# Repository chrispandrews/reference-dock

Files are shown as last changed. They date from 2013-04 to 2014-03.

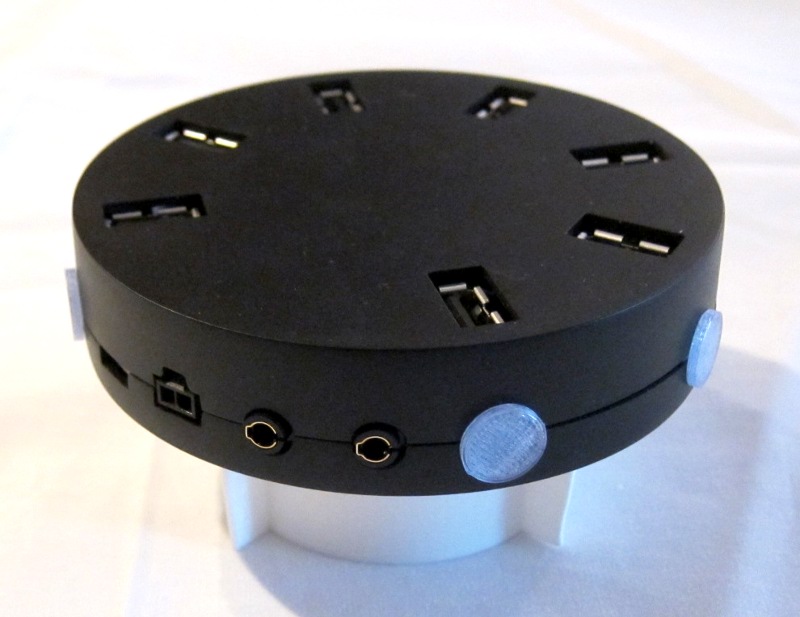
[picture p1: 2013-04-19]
docs/Dock_scaled.JPG

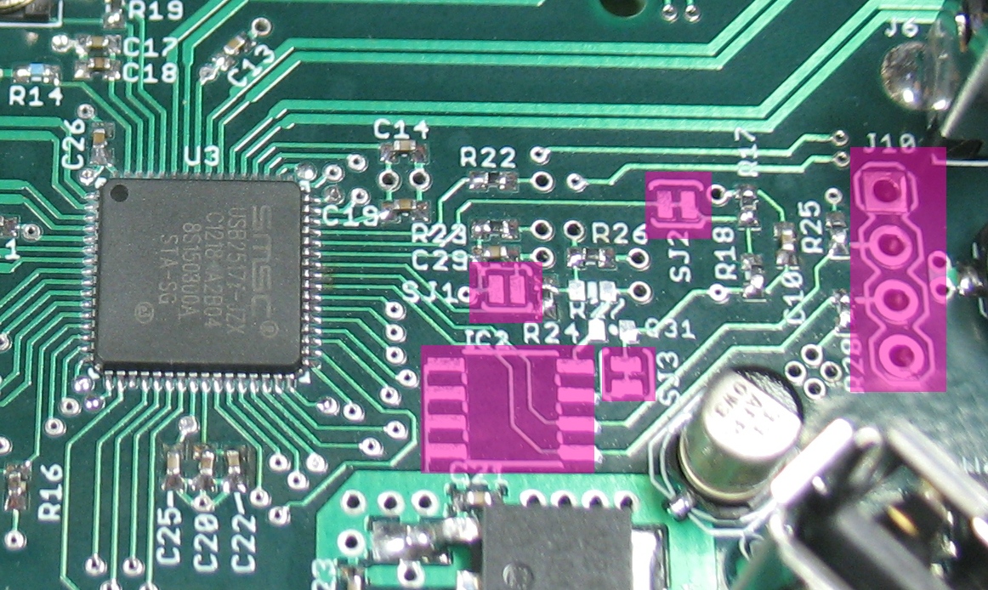
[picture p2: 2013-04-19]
docs/Dock_jumpers.JPG

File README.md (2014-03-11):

OpenXC Dock
===========

This repository is a part of the [OpenXC][] project.

This repository contains the documentation and open source design files for an
example OpenXC accessory dock, originally created by Ford.

The OpenXC Dock is a hub for connecting multiple USB accessories to an Android
tablet or phone. Since each accessory uses USB to communicate with the host, the
Dock is essentially a USB hub. The Dock receives power from the vehicle, and
regulates this power to a steady +5V for use by the accessory.

There is a [gallery of
photos](https://plus.google.com/photos/108408483770573977605/albums/5989365070748059233)
of the prototype dock.

### Buttons, Headers, Jumpers

*	JP2 - This jumper connects the +5V pin of the USB Micro connector to the +5V
	supply on the Dock. Connected by default. This enables charging of the
	Android device as well as standalone Dock usage with a PC.
*	SJ1 - USB hub reset - short this jumper to keep the USB hub in reset.
	Normally open.
*	SJ2 - Allows the USB hub to sense it's power state from the USB Micro
	connector. Normally closed by trace.
*	J10 - I2C - Exposes the i2c bus used by the USB hub for configuration
*	R35 - ID Resistor - For use with an Android device that expects a
	non-standard ID resistor in order to charge from USB OTG. The surface mount
	resistor R35 can be removed and a full-size 1/4W through hole resistor can
	be added instead.

### Known Issues

#### v0.3

*	USB D+ and D- swapped for downstream ports - An i2c EEPROM (AT24C02) was
	added to the board and soldered to J10. This allowed access to the PORT_SWAP
	register within the USB2517 hub, which enables the USB data lines to be
	swapped within the hub. Also
*	Downstream power ports are not enabled on hub poweron - The accessory USB
	connectors are not powered until a valid USB host has connected to the hub.
	Hub should be upgraded to a part with full Battery Charging support to
	enable this feature. The downstream power switches (U1, U2, U6, U7) were all
	reworked to remain permanently ON (each EN input trace was cut and the pin
	connected to +5V).
*	Downstream power ports will only flag a power fault when a host is
	connected. If an accessory malfunctions and draws too much power, the power
	switches will protect the accessory and Dock by limiting the current to
	500mA. When a host is connected, the LED for that port will light Red to
	indicate the fault. This does not occur when no host has been connected, so
	it's possible that a malfunctioning accessory will continue to draw ~500mA
	from the vehicle without alerting the user.

## License

Copyright (c) 2014 Ford Motor Company

The electrical and mechanical designs in this repository are available under the
[Creative Commons Attribution 4.0
International](http://creativecommons.org/licenses/by/4.0/deed.en_US) license.

[OpenXC]: http://openxcplatform.com

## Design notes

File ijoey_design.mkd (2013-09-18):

iJoey Design Guidelines
=======================

Below is a list of specifications for designing OpenXC iJoeys. These parameters
are specific for the components that get plugged into the size-specific Dock
ports.

**Outer Dimensions:**

* housing width: **16mm**

**Wall Thicknesses:**

* minimum case thickness: **2.54mm**
* minimum overlap thickness: **1.27mm** (overlap where two parts come together
  like clam shells)

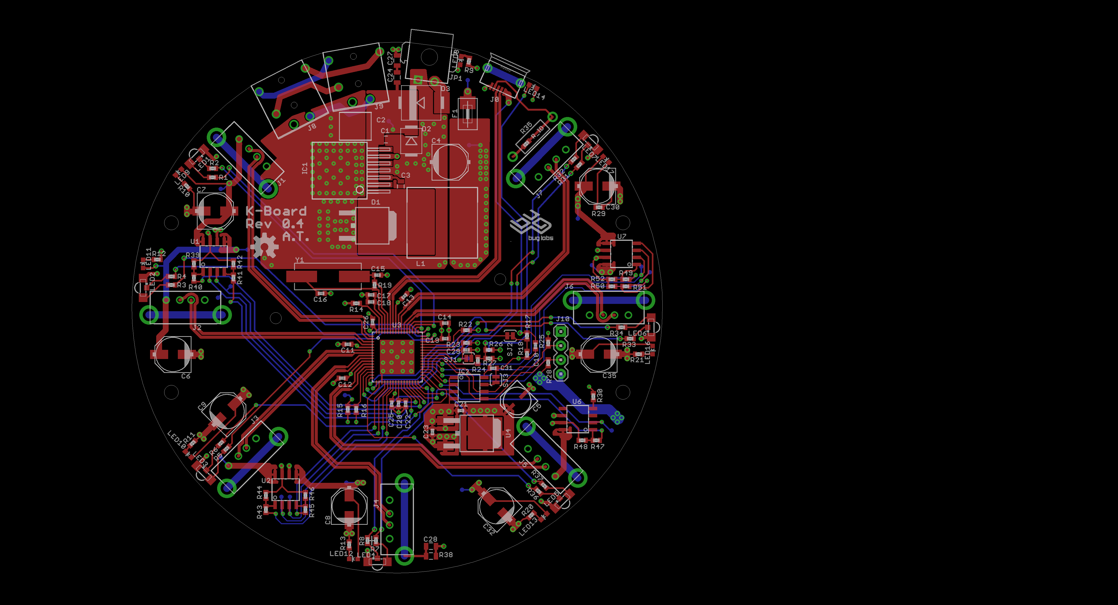
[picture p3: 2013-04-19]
schematics/Dock.brd.png

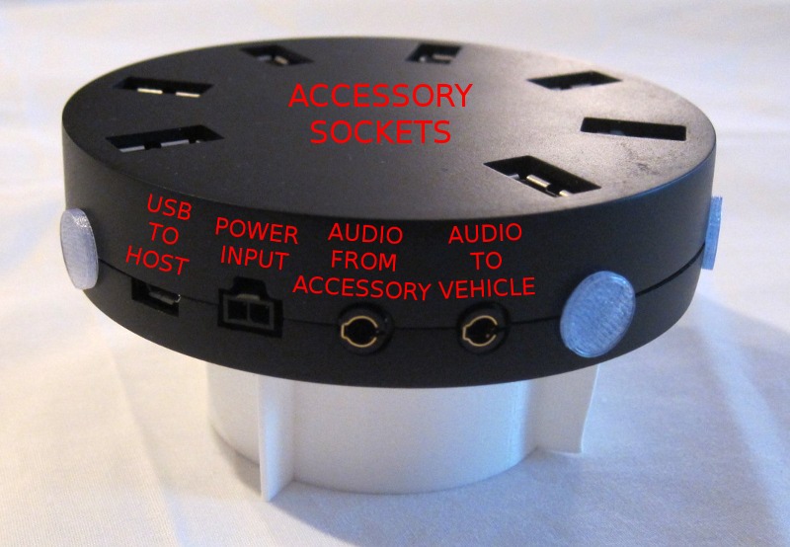
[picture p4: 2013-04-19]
docs/Dock_connectors.JPG

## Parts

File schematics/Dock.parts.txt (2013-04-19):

Partlist

Exported from K-Board.sch at 3/12/13 11:59 AM

EAGLE Version 6.1.0 Copyright (c) 1988-2012 CadSoft

Assembly variant: 

Part     Value                     Device                    Package          Library               Sheet

C1       GRM21BR71H105KA           CAP0805                   0805             BUG                   1
C2       C5750X7S2A106M            CAP2220                   2220             BUG                   1
C3       C0805C103K5RACTU          CAP0805                   0805             BUG                   1
C4       150u                      CAP_POLD                  PANASONIC_D      BUG                   1
C5       33u                       CAP_POLC                  PANASONIC_C      BUG                   1
C6       100u                      CAP_POLD                  PANASONIC_D      BUG                   1
C7       100u                      CAP_POLD                  PANASONIC_D      BUG                   1
C8       100u                      CAP_POLD                  PANASONIC_D      BUG                   1
C9       100u                      CAP_POLD                  PANASONIC_D      BUG                   1
C10      0.1                       CAP0402-CAP               0402-CAP         BUG                   1
C11      0.1                       CAP0402-CAP               0402-CAP         BUG                   1
C12      0.1                       CAP0402-CAP               0402-CAP         BUG                   1
C13      0.1                       CAP0402-CAP               0402-CAP         BUG                   1
C14      0.1                       CAP0402-CAP               0402-CAP         BUG                   1
C15      18p                       CAP0402-CAP               0402-CAP         BUG                   1
C16      18p                       CAP0402-CAP               0402-CAP         BUG                   1
C17      1                         CAP0402-CAP               0402-CAP         BUG                   1
C18      0.1                       CAP0402-CAP               0402-CAP         BUG                   1
C19      0.1                       CAP0402-CAP               0402-CAP         BUG                   1
C20      0.1                       CAP0402-CAP               0402-CAP         BUG                   1
C21      22n                       CAP0402-CAP               0402-CAP         BUG                   1
C22      1                         CAP0402-CAP               0402-CAP         BUG                   1
C23      0.1                       CAP0402-CAP               0402-CAP         BUG                   1
C24      0.47u                     CAP0805                   0805             BUG                   1
C25      0.1                       CAP0402-CAP               0402-CAP         BUG                   1
C26      0.1                       CAP0402-CAP               0402-CAP         BUG                   1
C27      0.47                      CAP0805                   0805             BUG                   1
C28      4.7n                      CAP0805                   0805             BUG                   1
C29      0.1                       CAP0402-CAP               0402-CAP         BUG                   1
C30      100u                      CAP_POLD                  PANASONIC_D      BUG                   1
C31      0.1                       CAP0402-CAP               0402-CAP         BUG                   1
C32      100u                      CAP_POLD                  PANASONIC_D      BUG                   1
C35      100u                      CAP_POLD                  PANASONIC_D      BUG                   1
D1       50WQ10FNPBF               DIODE_COMMON_CAT-DPAK     V-REG_DPACK      BUG                   1
D2       SMBJ36CA                  DIODE-TVS-SMB             SMB-DIODE        BUG                   1
D3       MBRS540T3G                DIODESMC/DO-214AB         SMC              SparkFun-DiscreteSemi 1
F1       MF-MSMF110/16-2           PTCFUSE-1812              1812             adafruit              1
IC1      LM22678                   LM22678                   TO-263           BUG                   1
IC2      ATMEL-AT24C02B-SS         ATMEL-AT24C02B-SS         SOIC8            BUG                   1
J0       USB_MINIB_SHIELD-10118193 USB_MINIB_SHIELD-10118193 10118193         BUG                   1
J1       USB-A-S-RA-VERT           USB-A-S-RA-VERT           USB-A-TH-VERT    BUG                   1
J2       USB-A-S-RA-VERT           USB-A-S-RA-VERT           USB-A-TH-VERT    BUG                   1
J3       USB-A-S-RA-VERT           USB-A-S-RA-VERT           USB-A-TH-VERT    BUG                   1
J4       USB-A-S-RA-VERT           USB-A-S-RA-VERT           USB-A-TH-VERT    BUG                   1
J5       USB-A-S-RA-VERT           USB-A-S-RA-VERT           USB-A-TH-VERT    BUG                   1
J6       USB-A-S-RA-VERT           USB-A-S-RA-VERT           USB-A-TH-VERT    BUG                   1
J7       USB-A-S-RA-VERT           USB-A-S-RA-VERT           USB-A-TH-VERT    BUG                   1
J8       Audio INPUT               AUDIO-JACK-4PSWSJ-43515   SJ-4351X         BUG                   1
J9       Audio OUTPUT              AUDIO-JACK-4PSWSJ-43515   SJ-4351X         BUG                   1
J10      IIC                       M04PTH                    1X04             SparkFun-Connectors   1
JP1      Power                     M022-1445055-2            2-1445055-2      BUG                   1
L1       SRR1208-6R5ML             INDUCTORSRR1208           SRR1208          BUG                   1
LED1     LED_2X_COMMON_ANODE       LED_2X_COMMON_ANODE       LED_DUAL_3MMX1MM BUG                   1
LED2     LED_2X_COMMON_ANODE       LED_2X_COMMON_ANODE       LED_DUAL_3MMX1MM BUG                   1
LED3     LED_2X_COMMON_ANODE       LED_2X_COMMON_ANODE       LED_DUAL_3MMX1MM BUG                   1
LED4     LED_2X_COMMON_ANODE       LED_2X_COMMON_ANODE       LED_DUAL_3MMX1MM BUG                   1
LED5     LED_2X_COMMON_ANODE       LED_2X_COMMON_ANODE       LED_DUAL_3MMX1MM BUG                   1
LED6     LED_2X_COMMON_ANODE       LED_2X_COMMON_ANODE       LED_DUAL_3MMX1MM BUG                   1
LED7     LED_2X_COMMON_ANODE       LED_2X_COMMON_ANODE       LED_DUAL_3MMX1MM BUG                   1
LED8                               LED0603                   LED-0603         BUG                   1
LED9                               LED0603                   LED-0603         BUG                   1
LED10                              LED0603                   LED-0603         BUG                   1
LED11                              LED0603                   LED-0603         BUG                   1
LED12                              LED0603                   LED-0603         BUG                   1
LED13                              LED0603                   LED-0603         BUG                   1
LED14                              LED0603                   LED-0603         BUG                   1
LED16                              LED0603                   LED-0603         BUG                   1
LED17                              LED0603                   LED-0603         BUG                   1
R1       110                       RESISTOR0402-RES          0402-RES         BUG                   1
R2       110                       RESISTOR0402-RES          0402-RES         BUG                   1
R3       110                       RESISTOR0402-RES          0402-RES         BUG                   1
R4       110                       RESISTOR0402-RES          0402-RES         BUG                   1
R5       110                       RESISTOR0402-RES          0402-RES         BUG                   1
R6       110                       RESISTOR0402-RES          0402-RES         BUG                   1
R7       110                       RESISTOR0402-RES          0402-RES         BUG                   1
R8       110                       RESISTOR0402-RES          0402-RES         BUG                   1
R9       330                       RESISTOR0402-RES          0402-RES         BUG                   1
R10      330                       RESISTOR0402-RES          0402-RES         BUG                   1
R11      330                       RESISTOR0402-RES          0402-RES         BUG                   1
R12      330                       RESISTOR0402-RES          0402-RES         BUG                   1
R13      330                       RESISTOR0402-RES          0402-RES         BUG                   1
R14      12k-1%                    RESISTOR0402-RES          0402-RES         BUG                   1
R15      10k                       RESISTOR0402-RES          0402-RES         BUG                   1
R16      DNP                       RESISTOR0402-RES          0402-RES         BUG                   1
R17      100k                      RESISTOR0402-RES          0402-RES         BUG                   1
R18      100k                      RESISTOR0402-RES          0402-RES         BUG                   1
R19      1M                        RESISTOR0402-RES          0402-RES         BUG                   1
R20      330                       RESISTOR0402-RES          0402-RES         BUG                   1
R21      330                       RESISTOR0402-RES          0402-RES         BUG                   1
R22      10k                       RESISTOR0402-RES          0402-RES         BUG                   1
R23      100k                      RESISTOR0402-RES          0402-RES         BUG                   1
R24      330                       RESISTOR0402-RES          0402-RES         BUG                   1
R25      10k                       RESISTOR0402-RES          0402-RES         BUG                   1
R26      100k                      RESISTOR0402-RES          0402-RES         BUG                   1
R27      DNP                       RESISTOR0402-RES          0402-RES         BUG                   1
R28      10k                       RESISTOR0402-RES          0402-RES         BUG                   1
R29      330                       RESISTOR0402-RES          0402-RES         BUG                   1
R30      10k                       RESISTOR0402-RES          0402-RES         BUG                   1
R31      110                       RESISTOR0402-RES          0402-RES         BUG                   1
R32      110                       RESISTOR0402-RES          0402-RES         BUG                   1
R33      110                       RESISTOR0402-RES          0402-RES         BUG                   1
R34      110                       RESISTOR0402-RES          0402-RES         BUG                   1
R35      124k                      RESISTOR0402-RES          0402-RES         BUG                   1
R35B     R_ID                      RESISTORPTH-1/4W          AXIAL-0.4        BUG                   1
R36      110                       RESISTOR0402-RES          0402-RES         BUG                   1
R37      110                       RESISTOR0402-RES          0402-RES         BUG                   1
R38      1M                        RESISTOR0805-RES          0805             BUG                   1
R39      0                         RESISTOR0402-RES          0402-RES         BUG                   1
R40      DNP                       RESISTOR0402-RES          0402-RES         BUG                   1
R41      DNP                       RESISTOR0402-RES          0402-RES         BUG                   1
R42      0                         RESISTOR0402-RES          0402-RES         BUG                   1
R43      DNP                       RESISTOR0402-RES          0402-RES         BUG                   1
R44      0                         RESISTOR0402-RES          0402-RES         BUG                   1
R45      DNP                       RESISTOR0402-RES          0402-RES         BUG                   1
R46      0                         RESISTOR0402-RES          0402-RES         BUG                   1
R47      DNP                       RESISTOR0402-RES          0402-RES         BUG                   1
R48      0                         RESISTOR0402-RES          0402-RES         BUG                   1
R49      DNP                       RESISTOR0402-RES          0402-RES         BUG                   1
R50      0                         RESISTOR0402-RES          0402-RES         BUG                   1
R51      DNP                       RESISTOR0402-RES          0402-RES         BUG                   1
R52      0                         RESISTOR0402-RES          0402-RES         BUG                   1
SJ1      OPEN                      SOLDERJUMPERNO            SJ_2S-NO         SparkFun-Passives     1
SJ2      CLOSED                    SOLDERJUMPERTRACE         SJ_2S-TRACE      SparkFun-Passives     1
SJ3      CLOSED                    SOLDERJUMPERTRACE         SJ_2S-TRACE      SparkFun-Passives     1
TP1      RESET                     TEST-POINT3               PAD.03X.03       BUG                   1
TP2      +5V                       TEST-POINT3               PAD.03X.03       BUG                   1
TP3      +12V                      TEST-POINT3               PAD.03X.03       BUG                   1
TP4      VBUS                      TEST-POINT3               PAD.03X.03       BUG                   1
TP5      CFG1                      TEST-POINT3               PAD.03X.03       BUG                   1
TP6      CFG2                      TEST-POINT3               PAD.03X.03       BUG                   1
TP7      ERR0                      TEST-POINT3               PAD.03X.03       BUG                   1
TP8      PWR0                      TEST-POINT3               PAD.03X.03       BUG                   1
TP9      ERR1                      TEST-POINT3               PAD.03X.03       BUG                   1
TP10     PWR1                      TEST-POINT3               PAD.03X.03       BUG                   1
TP11     ERR2                      TEST-POINT3               PAD.03X.03       BUG                   1
TP12     ERR3                      TEST-POINT3               PAD.03X.03       BUG                   1
TP13     PWR2                      TEST-POINT3               PAD.03X.03       BUG                   1
TP14     PWR3                      TEST-POINT3               PAD.03X.03       BUG                   1
TP15     ERR4                      TEST-POINT3               PAD.03X.03       BUG                   1
TP16     PWR4                      TEST-POINT3               PAD.03X.03       BUG                   1
TP17     ERR5                      TEST-POINT3               PAD.03X.03       BUG                   1
TP18     ERR6                      TEST-POINT3               PAD.03X.03       BUG                   1
TP19     PWR5                      TEST-POINT3               PAD.03X.03       BUG                   1
TP20     PWR6                      TEST-POINT3               PAD.03X.03       BUG                   1
U1                                 MIC2026                   SOIC8            BUG                   1
U2                                 MIC2026                   SOIC8            BUG                   1
U3       USB2517                   USB2517                   QFN-64-PAD       BUG                   1
U4       TLE4284DV33               V_REG_317DPACK            V-REG_DPACK      BUG                   1
U6                                 MIC2026                   SOIC8            BUG                   1
U7                                 MIC2026                   SOIC8            BUG                   1
Y1       24M                       CRYSTAL                   HC49USX          BUG                   1

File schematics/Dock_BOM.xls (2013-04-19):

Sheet: BOM
Part | Value | Package | For Antonio | Manu | Part # | Volt/Precision | Other | Link | Cost/1k
C1 | 1u | 0805 |  | Murata | GRM21BR71H105KA | X7R | 50V | http://ca.mouser.com/ProductDetail/Murata/GRM21BR71H105KA12L/ | 0.139
C2 | 10u | 2220 |  | TDK | C5750X7S2A106M | X7S | 100V | http://ca.mouser.com/ProductDetail/TDK/C5750X7S2A106M/ | 1.34
C3 | 10n | 0805 |  | Kemet | C0805C103K5RACTU | X7R | 50V | http://ca.mouser.com/ProductDetail/Kemet/C0805C103K5RACTU/ | 0.009
C4 | 150u | PANASONIC_D | YES | United Chemi-Con | APXE100ARA151MF80G | 10V |  | http://www.digikey.com/product-detail/en/APXE100ARA151MF80G/565-3201-1-ND/1826741 | 0.544
C5 | 33u | PANASONIC_C | YES | Panasonic | EEE-FPA330UAR | 10V | ESR 0.850 | http://ca.mouser.com/ProductDetail/Panasonic-Electronic-Components/EEE-FPA330UAR/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 | 0.17
C6 | 100u | PANASONIC_D | YES | United Chemi-Con | APXK160ARA101MF61G | 16V | ESR 0.024 | http://ca.mouser.com/ProductDetail/United-Chemi-Con/APXK160ARA101MF61G/ | 0.316
C7 | 100u | PANASONIC_D | YES | United Chemi-Con | APXK160ARA101MF61G | 16V | ESR 0.024 | http://ca.mouser.com/ProductDetail/United-Chemi-Con/APXK160ARA101MF61G/ | 0.316
C8 | 100u | PANASONIC_D | YES | United Chemi-Con | APXK160ARA101MF61G | 16V | ESR 0.024 | http://ca.mouser.com/ProductDetail/United-Chemi-Con/APXK160ARA101MF61G/ | 0.316
C9 | 100u | PANASONIC_D | YES | United Chemi-Con | APXK160ARA101MF61G | 16V | ESR 0.024 | http://ca.mouser.com/ProductDetail/United-Chemi-Con/APXK160ARA101MF61G/ | 0.316
C10 | 0.1 | 0402-CAP |  | Murata | GRM155R71C104JA88D | X7R | 16V | http://ca.mouser.com/ProductDetail/Murata/GRM155R71C104JA88D/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 | 0.009
C11 | 0.1 | 0402-CAP |  | Murata | GRM155R71C104JA88D | X7R | 16V | http://ca.mouser.com/ProductDetail/Murata/GRM155R71C104JA88D/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 | 0.009
C12 | 0.1 | 0402-CAP |  | Murata | GRM155R71C104JA88D | X7R | 16V | http://ca.mouser.com/ProductDetail/Murata/GRM155R71C104JA88D/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 | 0.009
C13 | 0.1 | 0402-CAP |  | Murata | GRM155R71C104JA88D | X7R | 16V | http://ca.mouser.com/ProductDetail/Murata/GRM155R71C104JA88D/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 | 0.009
C14 | 0.1 | 0402-CAP |  | Murata | GRM155R71C104JA88D | X7R | 16V | http://ca.mouser.com/ProductDetail/Murata/GRM155R71C104JA88D/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 | 0.009
C15 | 18p | 0402-CAP |  | Murata | GRM1555C1H180GA01D | C0G | 50V | http://ca.mouser.com/ProductDetail/Murata/GRM1555C1H180GA01D/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 | 0.011
C16 | 18p | 0402-CAP |  | Murata | GRM1555C1H180GA01D | C0G | 50V | http://ca.mouser.com/ProductDetail/Murata/GRM1555C1H180GA01D/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 | 0.011
C17 | 1 | 0402-CAP |  | Murata | GRM155R60J105KE19D | X5R | 6.3V | http://ca.mouser.com/ProductDetail/Murata/GRM155R60J105KE19D/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 | 0.015
C18 | 0.1 | 0402-CAP |  | Murata | GRM155R71C104JA88D | X7R | 16V | http://ca.mouser.com/ProductDetail/Murata/GRM155R71C104JA88D/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 | 0.009
C19 | 0.1 | 0402-CAP |  | Murata | GRM155R71C104JA88D | X7R | 16V | http://ca.mouser.com/ProductDetail/Murata/GRM155R71C104JA88D/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 | 0.009
C20 | 0.1 | 0402-CAP |  | Murata | GRM155R71C104JA88D | X7R | 16V | http://ca.mouser.com/ProductDetail/Murata/GRM155R71C104JA88D/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 | 0.009
C21 | 22n | 0402-CAP |  | Murata | GRM155R71C223KA01J | X7R | 16V | http://ca.mouser.com/ProductDetail/Murata/GRM155R71C223KA01J/ | 0.007
C22 | 1 | 0402-CAP |  | Murata | GRM155R60J105KE19D | X5R | 6.3V | http://ca.mouser.com/ProductDetail/Murata/GRM155R60J105KE19D/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 | 0.05
C23 | 0.1 | 0402-CAP |  | Murata | GRM155R71C104JA88D | X7R | 16V | http://ca.mouser.com/ProductDetail/Murata/GRM155R71C104JA88D/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 | 0.009
C24 | 0.47u | 0805 |  | Kemet | C0805C474K5RACTU | X7R | 50V | http://ca.mouser.com/ProductDetail/Kemet/C0805C474K5RACTU/?qs=sGAEpiMZZMvQvaS66kI3TgtI6N2Tjchx5p5dz6QvtNQ%3d | 0.063
C25 | 0.1 | 0402-CAP |  | Murata | GRM155R71C104JA88D | X7R | 16V | http://ca.mouser.com/ProductDetail/Murata/GRM155R71C104JA88D/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 | 0.009
C26 | 0.1 | 0402-CAP |  | Murata | GRM155R71C104JA88D | X7R | 16V | http://ca.mouser.com/ProductDetail/Murata/GRM155R71C104JA88D/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 | 0.009
C27 | 0.47 | 0805 |  | Kemet | C0805C474K5RACTU | X7R | 50V | http://ca.mouser.com/ProductDetail/Kemet/C0805C474K5RACTU/?qs=sGAEpiMZZMvQvaS66kI3TgtI6N2Tjchx5p5dz6QvtNQ%3d | 0.063
C28 | 4.7n | CAP0805 |  | Kemet | C0805V472KDRACTU | X7R | 1000V | http://ca.mouser.com/ProductDetail/Kemet/C0805V472KDRACTU/?qs=sGAEpiMZZMvQvaS66kI3TgOpKuqDqscl2NxQ1iIoH6Y%3d | 0.064
C29 | 0.1 | 0402-CAP |  | Murata | GRM155R71C104JA88D | X7R | 16V | http://ca.mouser.com/ProductDetail/Murata/GRM155R71C104JA88D/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 | 0.009
C30 | 100u | PANASONIC_D | YES | United Chemi-Con | APXK160ARA101MF61G | 16V | ESR 0.024 | http://ca.mouser.com/ProductDetail/United-Chemi-Con/APXK160ARA101MF61G/ | 0.316
C31 | 0.1 | 0402-CAP |  |  |  | DNP |  | http://ca.mouser.com/ProductDetail/Murata/GRM155R71C104JA88D/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 | 0.009
C32 | 100u | PANASONIC_D | YES | United Chemi-Con | APXK160ARA101MF61G | 16V | ESR 0.024 | http://ca.mouser.com/ProductDetail/United-Chemi-Con/APXK160ARA101MF61G/ | 0.316
C35 | 100u | PANASONIC_D | YES | United Chemi-Con | APXK160ARA101MF61G | 16V | ESR 0.024 | http://ca.mouser.com/ProductDetail/United-Chemi-Con/APXK160ARA101MF61G/ | 0.316
D1 | 50WQ10FNPBF | DPACK |  | Vishay | 50WQ10FNPBF | 100V | 5.5A | http://ca.mouser.com/ProductDetail/Vishay-Semiconductors/VS-50WQ10FNPBF/ | 0.668
D2 | SMBJ36CA | SMB-DIODE |  | Bourns | SMBJ36CA | 40V | 600W | http://ca.mouser.com/ProductDetail/Bourns/SMBJ36CA/ | 0.142
D3 | MBRS540T3G | SMC/DO-210AB |  | On Semi | MBRS540T3G | 40V | 5A | http://ca.mouser.com/ProductDetail/ON-Semiconductor/MBRS540T3G/ | 0.26
F1 | MF-MSMF110/16-2 | 1812 |  | Bourns | MF-MSMF110/16-2 | 16V | 1.1A | http://ca.mouser.com/ProductDetail/Bourns/MF-MSMF110-16-2/?qs=wksszfECgvir54ST3ixUHA== | 0.342
IC1 | LM22678 | TO-263 |  | TI | LM22678 | 5V | 5A | http://www.digikey.com/product-detail/en/LM22678TJE-5.0%2FNOPB/LM22678TJE-5.0%2FNOPBCT-ND/1950803 | 2.97
IC2 | ATMEL-AT24C02B-SS | SOIC8 |  |  |  | DNP |  | http://ca.mouser.com/ProductDetail/Atmel/AT24C02C-SSHM-T/?qs=sGAEpiMZZMuVhdAcoizlRQNkUaWV9UcRnXRDtRnjoSA%3d
J0 | USB_MINIB_SHIELD | 10118193 | YES | FCI | 10118193-0001LF | 5V |  | http://ca.mouser.com/ProductDetail/FCI/10118193-0001LF/?qs=sGAEpiMZZMuhucAexPYLesFMAgXhqips | 0.21
J1 | USB-A-S-RA-VERT | USB-A-TH-VERT | YES | TE Connectivity | 1734366-1 | 5V | 1A | http://ca.mouser.com/ProductDetail/TE-Connectivity/1734366-1/ | 0.631
J2 | USB-A-S-RA-VERT | USB-A-TH-VERT | YES | TE Connectivity | 1734366-1 | 5V | 1A | http://ca.mouser.com/ProductDetail/TE-Connectivity/1734366-1/ | 0.631
J3 | USB-A-S-RA-VERT | USB-A-TH-VERT | YES | TE Connectivity | 1734366-1 | 5V | 1A | http://ca.mouser.com/ProductDetail/TE-Connectivity/1734366-1/ | 0.631
J4 | USB-A-S-RA-VERT | USB-A-TH-VERT | YES | TE Connectivity | 1734366-1 | 5V | 1A | http://ca.mouser.com/ProductDetail/TE-Connectivity/1734366-1/ | 0.631
J5 | USB-A-S-RA-VERT | USB-A-TH-VERT | YES | TE Connectivity | 1734366-1 | 5V | 1A | http://ca.mouser.com/ProductDetail/TE-Connectivity/1734366-1/ | 0.631
J6 | USB-A-S-RA-VERT | USB-A-TH-VERT | YES | TE Connectivity | 1734366-1 | 5V | 1A | http://ca.mouser.com/ProductDetail/TE-Connectivity/1734366-1/ | 0.631
J7 | USB-A-S-RA-VERT | USB-A-TH-VERT | YES | TE Connectivity | 1734366-1 | 5V | 1A | http://ca.mouser.com/ProductDetail/TE-Connectivity/1734366-1/ | 0.631
J8 | Audio INPUT | AUDIO-JACK | YES | CUI Inc | SJ-43514 |  | 4 Conductor | http://www.digikey.com/product-detail/en/SJ-43514/CP-43514-ND/368146 | 0.552
J9 | Audio OUTPUT | AUDIO-JACK | YES | CUI Inc | SJ-43514 |  | 4 Conductor | http://www.digikey.com/product-detail/en/SJ-43514/CP-43514-ND/368146 | 0.552
J10 | IIC | 1X04 |  |  |  | DNP
JP1 | Power | 2-1445055-2 | YES | TE Connectivity | 2-1445055-2 | 5A |  | http://www.digikey.com/scripts/DkSearch/dksus.dll?WT.z_header=search_go%E2%8C%A9=en&x=20&y=11&cur=USD | 0.422
L1 | 6.5uH | SRR1208 | YES | Bourns | SRR1208-6R5ML | 6A | 0.018 Ohms | http://ca.mouser.com/ProductDetail/Bourns/SRR1208-6R5ML/ | 0.449
LED1 | Red/Green | 3MMX1MM | YES | Kingbright | APBA3010SURKCGKC-GX | 2.1V Gr 1.95V R |  | http://www.digikey.com/product-detail/en/APBA3010SURKCGKC-GX/754-1587-1-ND/2757895 | 0.202
LED2 | Red/Green | 3MMX1MM | YES | Kingbright | APBA3010SURKCGKC-GX | 2.1V Gr 1.95V R |  | http://www.digikey.com/product-detail/en/APBA3010SURKCGKC-GX/754-1587-1-ND/2757895 | 0.202
LED3 | Red/Green | 3MMX1MM | YES | Kingbright | APBA3010SURKCGKC-GX | 2.1V Gr 1.95V R |  | http://www.digikey.com/product-detail/en/APBA3010SURKCGKC-GX/754-1587-1-ND/2757895 | 0.202
LED4 | Red/Green | 3MMX1MM | YES | Kingbright | APBA3010SURKCGKC-GX | 2.1V Gr 1.95V R |  | http://www.digikey.com/product-detail/en/APBA3010SURKCGKC-GX/754-1587-1-ND/2757895 | 0.202
LED5 | Red/Green | 3MMX1MM | YES | Kingbright | APBA3010SURKCGKC-GX | 2.1V Gr 1.95V R |  | http://www.digikey.com/product-detail/en/APBA3010SURKCGKC-GX/754-1587-1-ND/2757895 | 0.202
LED6 | Red/Green | 3MMX1MM | YES | Kingbright | APBA3010SURKCGKC-GX | 2.1V Gr 1.95V R |  | http://www.digikey.com/product-detail/en/APBA3010SURKCGKC-GX/754-1587-1-ND/2757895 | 0.202
LED7 | Red/Green | 3MMX1MM | YES | Kingbright | APBA3010SURKCGKC-GX | 2.1V Gr 1.95V R |  | http://www.digikey.com/product-detail/en/APBA3010SURKCGKC-GX/754-1587-1-ND/2757895 | 0.202
LED8 | Red | LED-0603 | YES | Lumex | SML-LX0603SRW-TR | 1.7V | 30mA | http://ca.mouser.com/ProductDetail/Lumex/SML-LX0603SRW-TR/?qs=sGAEpiMZZMtEjy7lsqBi5RJSiXBATNyvPQrK1QY4BhE%3d | 0.1
LED9 | Red | LED-0603 |  |  |  | DNP |  | http://ca.mouser.com/ProductDetail/Lumex/SML-LX0603SRW-TR/?qs=sGAEpiMZZMtEjy7lsqBi5RJSiXBATNyvPQrK1QY4BhE%3d | 0.1
LED10 | Red | LED-0603 |  |  |  | DNP |  | http://ca.mouser.com/ProductDetail/Lumex/SML-LX0603SRW-TR/?qs=sGAEpiMZZMtEjy7lsqBi5RJSiXBATNyvPQrK1QY4BhE%3d | 0.1
LED11 | Red | LED-0603 |  |  |  | DNP |  | http://ca.mouser.com/ProductDetail/Lumex/SML-LX0603SRW-TR/?qs=sGAEpiMZZMtEjy7lsqBi5RJSiXBATNyvPQrK1QY4BhE%3d | 0.1
LED12 | Red | LED-0603 |  |  |  | DNP |  | http://ca.mouser.com/ProductDetail/Lumex/SML-LX0603SRW-TR/?qs=sGAEpiMZZMtEjy7lsqBi5RJSiXBATNyvPQrK1QY4BhE%3d | 0.1
LED13 | Red | LED-0603 |  |  |  | DNP |  | http://ca.mouser.com/ProductDetail/Lumex/SML-LX0603SRW-TR/?qs=sGAEpiMZZMtEjy7lsqBi5RJSiXBATNyvPQrK1QY4BhE%3d | 0.1
LED14 | Green | LED-0603 | YES | Lumex | SML-LX0603SUGW-TR | 2.2v | 25mA | http://ca.mouser.com/ProductDetail/Lumex/SML-LX0603SUGW-TR/?qs=sGAEpiMZZMtEjy7lsqBi5RJSiXBATNyvW8f9Im9YZTw%3d | 0.353
LED16 | Red | LED-0603 |  |  |  | DNP |  | http://ca.mouser.com/ProductDetail/Lumex/SML-LX0603SRW-TR/?qs=sGAEpiMZZMtEjy7lsqBi5RJSiXBATNyvPQrK1QY4BhE%3d | 0.1
LED17 | Red | LED-0603 |  |  |  | DNP |  | http://ca.mouser.com/ProductDetail/Lumex/SML-LX0603SRW-TR/?qs=sGAEpiMZZMtEjy7lsqBi5RJSiXBATNyvPQrK1QY4BhE%3d | 0.1
R1 | 110 | 0402-RES | YES | KOA Speer | RK73B1ETTP111J | 5.00% | 63mW | http://ca.mouser.com/ProductDetail/KOA-Speer/RK73B1ETTP111J/?qs=sGAEpiMZZMvdGkrng054t2G6xR8IJpNvfFWU1uOWxNk%3d | 0.018
R2 | 110 | 0402-RES | YES | KOA Speer | RK73B1ETTP111J | 105.00% | 63mW | http://ca.mouser.com/ProductDetail/KOA-Speer/RK73B1ETTP111J/?qs=sGAEpiMZZMvdGkrng054t2G6xR8IJpNvfFWU1uOWxNk%3d | 0.018
R3 | 110 | 0402-RES | YES | KOA Speer | RK73B1ETTP111J | 205.00% | 63mW | http://ca.mouser.com/ProductDetail/KOA-Speer/RK73B1ETTP111J/?qs=sGAEpiMZZMvdGkrng054t2G6xR8IJpNvfFWU1uOWxNk%3d | 0.018
R4 | 110 | 0402-RES | YES | KOA Speer | RK73B1ETTP111J | 305.00% | 63mW | http://ca.mouser.com/ProductDetail/KOA-Speer/RK73B1ETTP111J/?qs=sGAEpiMZZMvdGkrng054t2G6xR8IJpNvfFWU1uOWxNk%3d | 0.018
R5 | 110 | 0402-RES | YES | KOA Speer | RK73B1ETTP111J | 405.00% | 63mW | http://ca.mouser.com/ProductDetail/KOA-Speer/RK73B1ETTP111J/?qs=sGAEpiMZZMvdGkrng054t2G6xR8IJpNvfFWU1uOWxNk%3d | 0.018
R6 | 110 | 0402-RES | YES | KOA Speer | RK73B1ETTP111J | 505.00% | 63mW | http://ca.mouser.com/ProductDetail/KOA-Speer/RK73B1ETTP111J/?qs=sGAEpiMZZMvdGkrng054t2G6xR8IJpNvfFWU1uOWxNk%3d | 0.018
R7 | 110 | 0402-RES | YES | KOA Speer | RK73B1ETTP111J | 605.00% | 63mW | http://ca.mouser.com/ProductDetail/KOA-Speer/RK73B1ETTP111J/?qs=sGAEpiMZZMvdGkrng054t2G6xR8IJpNvfFWU1uOWxNk%3d | 0.018
R8 | 110 | 0402-RES | YES | KOA Speer | RK73B1ETTP111J | 705.00% | 63mW | http://ca.mouser.com/ProductDetail/KOA-Speer/RK73B1ETTP111J/?qs=sGAEpiMZZMvdGkrng054t2G6xR8IJpNvfFWU1uOWxNk%3d | 0.018
R9 | 330 | 0402-RES | YES | KOA Speer | RK73B1ETTP331J | 5.00% | 63mW | http://ca.mouser.com/ProductDetail/KOA-Speer/RK73B1ETTP331J/ | 0.018
R10 | 330 | 0402-RES |  |  |  | DNP |  | http://ca.mouser.com/ProductDetail/KOA-Speer/RK73B1ETTP331J/ | 0.018
R11 | 330 | 0402-RES |  |  |  | DNP |  | http://ca.mouser.com/ProductDetail/KOA-Speer/RK73B1ETTP331J/ | 0.018
R12 | 330 | 0402-RES |  |  |  | DNP |  | http://ca.mouser.com/ProductDetail/KOA-Speer/RK73B1ETTP331J/ | 0.018
R13 | 330 | 0402-RES |  |  |  | DNP |  | http://ca.mouser.com/ProductDetail/KOA-Speer/RK73B1ETTP331J/ | 0.018
R14 | 12k-1% | 0402-RES |  | KOA Speer | RK73H1ETTP1202F | 1.00% | 63mW | http://ca.mouser.com/ProductDetail/KOA-Speer/RK73H1ETTP1202F/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 | 0.016
R15 | 10k | 0402-RES |  | KOA Speer | RK73B1ETTP103J | 5.00% | 63mW | http://ca.mouser.com/ProductDetail/KOA-Speer/RK73B1ETTP103J/ | 0.018
R16 | DNP | 0402-RES |  |  |  | DNP
R17 | 100k | 0402-RES |  | KOA Speer | RK73B1ETTP104J | 5.00% | 63mW | http://ca.mouser.com/ProductDetail/KOA-Speer/RK73B1ETTP104J/ | 0.018
R18 | 100k | 0402-RES |  | KOA Speer | RK73B1ETTP104J | 5.00% | 63mW | http://ca.mouser.com/ProductDetail/KOA-Speer/RK73B1ETTP104J/ | 0.018
R19 | 1M | 0402-RES |  | KOA Speer | RK73B1ETTP105J | 5.00% | 63mW | http://ca.mouser.com/ProductDetail/KOA-Speer/RK73B1ETTP105J/ | 0.018
R20 | 330 | 0402-RES |  |  |  | DNP |  | http://ca.mouser.com/ProductDetail/KOA-Speer/RK73B1ETTP331J/ | 0.018
R21 | 330 | 0402-RES |  |  |  | DNP |  | http://ca.mouser.com/ProductDetail/KOA-Speer/RK73B1ETTP331J/ | 0.018
R22 | 10k | 0402-RES |  | KOA Speer | RK73B1ETTP103J | 5.00% | 63mW | http://ca.mouser.com/ProductDetail/KOA-Speer/RK73B1ETTP103J/ | 0.018
R23 | 100k | 0402-RES |  | KOA Speer | RK73B1ETTP104J | 5.00% | 63mW | http://ca.mouser.com/ProductDetail/KOA-Speer/RK73B1ETTP104J/ | 0.018
R24 | 330 | 0402-RES | YES | KOA Speer | RK73B1ETTP331J | 5.00% | 63mW | http://ca.mouser.com/ProductDetail/KOA-Speer/RK73B1ETTP331J/ | 0.018
R25 | 10k | 0402-RES |  | KOA Speer | RK73B1ETTP103J | 5.00% | 63mW | http://ca.mouser.com/ProductDetail/KOA-Speer/RK73B1ETTP103J/ | 0.018
R26 | 100k | 0402-RES |  | KOA Speer | RK73B1ETTP104J | 5.00% | 63mW | http://ca.mouser.com/ProductDetail/KOA-Speer/RK73B1ETTP104J/ | 0.018
R27 | DNP | 0402-RES |  |  |  | DNP
R28 | 10k | 0402-RES |  | KOA Speer | RK73B1ETTP103J | 5.00% | 63mW | http://ca.mouser.com/ProductDetail/KOA-Speer/RK73B1ETTP103J/ | 0.018
R29 | 330 | 0402-RES |  |  |  | DNP |  | http://ca.mouser.com/ProductDetail/KOA-Speer/RK73B1ETTP331J/ | 0.018
R30 | 10k | 0402-RES |  | KOA Speer | RK73B1ETTP103J | 5.00% | 63mW | http://ca.mouser.com/ProductDetail/KOA-Speer/RK73B1ETTP103J/ | 0.018
R31 | 110 | 0402-RES | YES | KOA Speer | RK73B1ETTP111J | 705.00% | 63mW | http://ca.mouser.com/ProductDetail/KOA-Speer/RK73B1ETTP111J/?qs=sGAEpiMZZMvdGkrng054t2G6xR8IJpNvfFWU1uOWxNk%3d | 0.018
R32 | 110 | 0402-RES | YES | KOA Speer | RK73B1ETTP111J | 705.00% | 63mW | http://ca.mouser.com/ProductDetail/KOA-Speer/RK73B1ETTP111J/?qs=sGAEpiMZZMvdGkrng054t2G6xR8IJpNvfFWU1uOWxNk%3d | 0.018
R33 | 110 | 0402-RES | YES | KOA Speer | RK73B1ETTP111J | 705.00% | 63mW | http://ca.mouser.com/ProductDetail/KOA-Speer/RK73B1ETTP111J/?qs=sGAEpiMZZMvdGkrng054t2G6xR8IJpNvfFWU1uOWxNk%3d | 0.018
R34 | 110 | 0402-RES | YES | KOA Speer | RK73B1ETTP111J | 705.00% | 63mW | http://ca.mouser.com/ProductDetail/KOA-Speer/RK73B1ETTP111J/?qs=sGAEpiMZZMvdGkrng054t2G6xR8IJpNvfFWU1uOWxNk%3d | 0.018
R35 | 124k | 0402-RES |  | KOA Speer | RK73H1ETTP1243F | 1.00% | 63mW | http://ca.mouser.com/ProductDetail/KOA-Speer/RK73H1ETTP1243F/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 | 0.016
R35B | R_ID | AXIAL-0.4 |  |  |  | DNP
R36 | 110 | 0402-RES | YES | KOA Speer | RK73B1ETTP111J | 705.00% | 63mW | http://ca.mouser.com/ProductDetail/KOA-Speer/RK73B1ETTP111J/?qs=sGAEpiMZZMvdGkrng054t2G6xR8IJpNvfFWU1uOWxNk%3d | 0.018
R37 | 110 | 0402-RES | YES | KOA Speer | RK73B1ETTP111J | 705.00% | 63mW | http://ca.mouser.com/ProductDetail/KOA-Speer/RK73B1ETTP111J/?qs=sGAEpiMZZMvdGkrng054t2G6xR8IJpNvfFWU1uOWxNk%3d | 0.018
R38 | 1M | 805 |  | KOA Speer | CRCW08051M00JNEAHP | 5.00% | 330mW | http://ca.mouser.com/ProductDetail/Vishay-Dale/CRCW08051M00JNEAHP/ | 0.062
R39 | 0 | 0402-RES |  | KOA Speer | RK73Z1ETTP | -% | 1W | http://ca.mouser.com/ProductDetail/KOA-Speer/RK73Z1ETTP/ | 0.021
R40 | DNP | 0402-RES |  |  |  | DNP |  | http://ca.mouser.com/ProductDetail/KOA-Speer/RK73Z1ETTP/ | 0.021
R41 | DNP | 0402-RES |  |  |  | DNP |  | http://ca.mouser.com/ProductDetail/KOA-Speer/RK73Z1ETTP/ | 0.021
R42 | 0 | 0402-RES |  | KOA Speer | RK73Z1ETTP | -% | 1W | http://ca.mouser.com/ProductDetail/KOA-Speer/RK73Z1ETTP/ | 0.021
R43 | DNP | 0402-RES |  |  |  | DNP |  | http://ca.mouser.com/ProductDetail/KOA-Speer/RK73Z1ETTP/ | 0.021
R44 | 0 | 0402-RES |  | KOA Speer | RK73Z1ETTP | -% | 1W | http://ca.mouser.com/ProductDetail/KOA-Speer/RK73Z1ETTP/ | 0.021
R45 | DNP | 0402-RES |  |  |  | DNP |  | http://ca.mouser.com/ProductDetail/KOA-Speer/RK73Z1ETTP/ | 0.021
R46 | 0 | 0402-RES |  | KOA Speer | RK73Z1ETTP | -% | 1W | http://ca.mouser.com/ProductDetail/KOA-Speer/RK73Z1ETTP/ | 0.021
R47 | DNP | 0402-RES |  |  |  | DNP |  | http://ca.mouser.com/ProductDetail/KOA-Speer/RK73Z1ETTP/ | 0.021
R48 | 0 | 0402-RES |  | KOA Speer | RK73Z1ETTP | -% | 1W | http://ca.mouser.com/ProductDetail/KOA-Speer/RK73Z1ETTP/ | 0.021
R49 | DNP | 0402-RES |  |  |  | DNP |  | http://ca.mouser.com/ProductDetail/KOA-Speer/RK73Z1ETTP/ | 0.021
R50 | 0 | 0402-RES |  | KOA Speer | RK73Z1ETTP | -% | 1W | http://ca.mouser.com/ProductDetail/KOA-Speer/RK73Z1ETTP/ | 0.021
R51 | DNP | 0402-RES |  |  |  | DNP |  | http://ca.mouser.com/ProductDetail/KOA-Speer/RK73Z1ETTP/ | 0.021
R52 | 0 | 0402-RES |  | KOA Speer | RK73Z1ETTP | -% | 1W | http://ca.mouser.com/ProductDetail/KOA-Speer/RK73Z1ETTP/ | 0.021
U1 |  | SOIC8 |  | Diodes Inc | AP2156SG-13 | 5.5V | 0.5A/ch | http://www.digikey.com/product-detail/en/AP2156SG-13/AP2156SGDICT-ND/2057320 | 0.387
U2 |  | SOIC8 |  | Diodes Inc | AP2156SG-13 | 5.5V | 0.5A/ch | http://www.digikey.com/product-detail/en/AP2156SG-13/AP2156SGDICT-ND/2057320 | 0.387
U3 | USB2517 | QFN-64-PAD |  | SMSC | USB2517I-JZX | 3.3v | 240mA | http://ca.mouser.com/ProductDetail/Microchip/USB2517I-JZX/ | 5.29
U4 | TLE4284DV33 | V-REG_DPACK |  | Infineon | TLE4284D V33 | 3.3V | 1A | http://www.digikey.ca/product-detail/en/TLE4284D%20V33/TLE4284D%20V33TR-ND/1016100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 | 1.025
U6 |  | SOIC8 |  | Diodes Inc | AP2156SG-13 | 5.5V | 0.5A/ch | http://www.digikey.com/product-detail/en/AP2156SG-13/AP2156SGDICT-ND/2057320 | 0.387
U7 |  | SOIC8 |  | Diodes Inc | AP2156SG-13 | 5.5V | 0.5A/ch | http://www.digikey.com/product-detail/en/AP2156SG-13/AP2156SGDICT-ND/2057320 | 0.387
Y1 | 24M | HC49USX | YES | ECS | ECS-240-12-5PX-TR | 50ppm | 12pF | http://www.mouser.com/ProductDetail/ECS/ECS-240-12-5PX-TR/ | 0.2

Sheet: PartsList
Part | Qty | Value | Package | Manu | Part # | Volt/Precision | Other | Distributor | Link | Supplier # | Cost/1k
C1 | 1 | 1u | 0805 | Murata | GRM21BR71H105KA | X7R | 50V | Mouser | http://ca.mouser.com/ProductDetail/Murata/GRM21BR71H105KA12L/ | 81-GRM21BR71H105KA2L | 0.139
C10-14,18-20,23,25,26,29 | 12 | 0.1 | 0402-CAP | Murata | GRM155R71C104JA88D | X7R | 16V | Mouser | http://ca.mouser.com/ProductDetail/Murata/GRM155R71C104JA88D/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 | 81-GRM155R71C104JA8D | 0.009
C15,16 | 2 | 18p | 0402-CAP | Murata | GRM1555C1H180GA01D | C0G | 50V | Mouser | http://ca.mouser.com/ProductDetail/Murata/GRM1555C1H180GA01D/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 | 81-GRM1555C1H180GA1D | 0.011
C17,22 | 2 | 1 | 0402-CAP | Murata | GRM155R60J105KE19D | X5R | 6.3V | Mouser | http://ca.mouser.com/ProductDetail/Murata/GRM155R60J105KE19D/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 | 81-GRM155R60J105KE19 | 0.015
C2 | 1 | 10u | 2220 | TDK | C5750X7S2A106M | X7S | 100V | Mouser | http://ca.mouser.com/ProductDetail/TDK/C5750X7S2A106M/ | 810-C5750X7S2A106M | 1.34
C21 | 1 | 22n | 0402-CAP | Murata | GRM155R71C223KA01J | X7R | 16V | Mouser | http://ca.mouser.com/ProductDetail/Murata/GRM155R71C223KA01J/ | 81-GRM155R71C223KA1J | 0.007
C24,27 | 2 | 0.47u | 0805 | Kemet | C0805C474K5RACTU | X7R | 50V | Mouser | http://ca.mouser.com/ProductDetail/Kemet/C0805C474K5RACTU/?qs=sGAEpiMZZMvQvaS66kI3TgtI6N2Tjchx5p5dz6QvtNQ%3d | 80-C0805C474K5R | 0.063
C28 | 1 | 4.7n | CAP0805 | Kemet | C0805V472KDRACTU | X7R | 1000V | Mouser | http://ca.mouser.com/ProductDetail/Kemet/C0805V472KDRACTU/?qs=sGAEpiMZZMvQvaS66kI3TgOpKuqDqscl2NxQ1iIoH6Y%3d | 80-C0805V472KDR | 0.064
C3 | 1 | 10n | 0805 | Kemet | C0805C103K5RACTU | X7R | 50V | Mouser | http://ca.mouser.com/ProductDetail/Kemet/C0805C103K5RACTU/ | 80-C0805C103K5R | 0.009
C30,32,35,6-9 | 7 | 100u | PANASONIC_D | United Chemi-Con | APXK160ARA101MF61G | 16V | ESR 0.024 | Mouser | http://ca.mouser.com/ProductDetail/United-Chemi-Con/APXK160ARA101MF61G/ | 661-APXK160A101MF61G | 0.316
C4 | 1 | 150u | PANASONIC_D | United Chemi-Con | APXE100ARA151MF80G | 10V |  | Digi-Key | http://www.digikey.com/product-detail/en/APXE100ARA151MF80G/565-3201-1-ND/1826741 | 565-3201-1-ND | 0.544
C5 | 1 | 33u | PANASONIC_C | Panasonic | EEE-FPA330UAR | 10V | ESR 0.850 | Mouser | http://ca.mouser.com/ProductDetail/Panasonic-Electronic-Components/EEE-FPA330UAR/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 | 667-EEE-FPA330UAR | 0.17
D1 | 1 | 50WQ10FNPBF | DPACK | Vishay | 50WQ10FNPBF | 100V | 5.5A | Mouser | http://ca.mouser.com/ProductDetail/Vishay-Semiconductors/VS-50WQ10FNPBF/ | 844-50WQ10FNPBF | 0.668
D2 | 1 | SMBJ36CA | SMB-DIODE | Bourns | SMBJ36CA | 40V | 600W | Mouser | http://ca.mouser.com/ProductDetail/Bourns/SMBJ36CA/ | 652-SMBJ36CA | 0.142
D3 | 1 | MBRS540T3G | SMC/DO-210AB | On Semi | MBRS540T3G | 40V | 5A | Mouser | http://ca.mouser.com/ProductDetail/ON-Semiconductor/MBRS540T3G/ | 863-MBRS540T3G | 0.26
F1 | 1 | MF-MSMF110/16-2 | 1812 | Bourns | MF-MSMF110/16-2 | 16V | 1.1A | Mouser | http://ca.mouser.com/ProductDetail/Bourns/MF-MSMF110-16-2/?qs=wksszfECgvir54ST3ixUHA== | 652-MF-MSMF110/16-2 | 0.342
IC1 | 1 | LM22678 | TO-263 | TI | LM22678 | 5V | 5A | Digi-Key | http://www.digikey.com/product-detail/en/LM22678TJE-5.0%2FNOPB/LM22678TJE-5.0%2FNOPBCT-ND/1950803 | LM22678TJE-5.0/NOPBCT-ND | 2.97
J0 | 1 | USB_MINIB_SHIELD | 10118193 | FCI | 10118193-0001LF | 5V |  | Mouser | http://ca.mouser.com/ProductDetail/FCI/10118193-0001LF/?qs=sGAEpiMZZMuhucAexPYLesFMAgXhqips | 649-10118193-0001LF | 0.21
J1-7 | 7 | USB-A-S-RA-VERT | USB-A-TH-VERT | TE Connectivity | 1734366-1 | 5V | 1A | Mouser | http://ca.mouser.com/ProductDetail/TE-Connectivity/1734366-1/ | 571-1734366-1 | 0.631
J8,9 | 2 | Audio INPUT | AUDIO-JACK | CUI Inc | SJ-43514 |  | 4 Conductor | Digi-Key | http://www.digikey.com/product-detail/en/SJ-43514/CP-43514-ND/368146 | CP-43514-ND | 0.552
JP1 | 1 | Power | 2-1445055-2 | TE Connectivity | 2-1445055-2 | 5A |  | Digi-Key | http://www.digikey.com/scripts/DkSearch/dksus.dll?WT.z_header=search_go%E2%8C%A9=en&x=20&y=11&cur=USD | A33207-ND | 0.422
L1 | 1 | 6.5uH | SRR1208 | Bourns | SRR1208-6R5ML | 6A | 0.018 Ohms | Mouser | http://ca.mouser.com/ProductDetail/Bourns/SRR1208-6R5ML/ | 652-SRR1208-6R5ML | 0.449
LED1,7 | 7 | Red/Green | 3MMX1MM | Kingbright | APBA3010SURKCGKC-GX | 2.1V Gr 1.95V R |  | Digi-Key | http://www.digikey.com/product-detail/en/APBA3010SURKCGKC-GX/754-1587-1-ND/2757895 | 754-1587-1-ND | 0.202
LED14 | 1 | Green | LED-0603 | Lumex | SML-LX0603SUGW-TR | 2.2v | 25mA | Mouser | http://ca.mouser.com/ProductDetail/Lumex/SML-LX0603SUGW-TR/?qs=sGAEpiMZZMtEjy7lsqBi5RJSiXBATNyvW8f9Im9YZTw%3d | 696-SML-LX0603SUGW | 0.353
LED8 | 1 | Red | LED-0603 | Lumex | SML-LX0603SRW-TR | 1.7V | 30mA | Mouser | http://ca.mouser.com/ProductDetail/Lumex/SML-LX0603SRW-TR/?qs=sGAEpiMZZMtEjy7lsqBi5RJSiXBATNyvPQrK1QY4BhE%3d | 696-SML-LX0603SRW | 0.1
R1-8,31-34,36,37 | 14 | 110 | 0402-RES | KOA Speer | RK73B1ETTP111J | 5.00% | 63mW | Mouser | http://ca.mouser.com/ProductDetail/KOA-Speer/RK73B1ETTP111J/?qs=sGAEpiMZZMvdGkrng054t2G6xR8IJpNvfFWU1uOWxNk%3d | 660-RK73B1ETTP111J | 0.018
R9-13,20,21,29 | 8 | 330 | 0402-RES | KOA Speer | RK73B1ETTP331J | 5.00% | 63mW | Mouser | http://ca.mouser.com/ProductDetail/KOA-Speer/RK73B1ETTP331J/ | 660-RK73B1ETTP331J | 0.018
R14 | 1 | 12k-1% | 0402-RES | KOA Speer | RK73H1ETTP1202F | 1.00% | 63mW | Mouser | http://ca.mouser.com/ProductDetail/KOA-Speer/RK73H1ETTP1202F/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 | 660-RK73H1ETTP1202F | 0.016
R15,22,25,28 | 4 | 10k | 0402-RES | KOA Speer | RK73B1ETTP103J | 5.00% | 63mW | Mouser | http://ca.mouser.com/ProductDetail/KOA-Speer/RK73B1ETTP103J/ | 660-RK73B1ETTP103J | 0.018
R17,18,23,26 | 4 | 100k | 0402-RES | KOA Speer | RK73B1ETTP104J | 5.00% | 63mW | Mouser | http://ca.mouser.com/ProductDetail/KOA-Speer/RK73B1ETTP104J/ | 660-RK73B1ETTP104J | 0.018
R19 | 1 | 1M | 0402-RES | KOA Speer | RK73B1ETTP105J | 5.00% | 63mW | Mouser | http://ca.mouser.com/ProductDetail/KOA-Speer/RK73B1ETTP105J/ | 660-RK73B1ETTP105J | 0.018
R30 | 1 | 10k | 0402-RES | KOA Speer | RK73B1ETTP103J | 5.00% | 63mW | Mouser | http://ca.mouser.com/ProductDetail/KOA-Speer/RK73B1ETTP103J/ | 660-RK73B1ETTP103J | 0.018
R35 | 1 | 124k | 0402-RES | KOA Speer | RK73H1ETTP1243F | 1.00% | 63mW | Mouser | http://ca.mouser.com/ProductDetail/KOA-Speer/RK73H1ETTP1243F/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 | 660-RK73H1ETTP1243F | 0.016
R38 | 1 | 1M | 805 | Vishay | CRCW08051M00JNEAHP | 5.00% | 330mW | Mouser | http://ca.mouser.com/ProductDetail/Vishay-Dale/CRCW08051M00JNEAHP/ | 71-CRCW08051M00JNEAH | 0.062
U1,2,6,7 | 4 |  | SOIC8 | Diodes Inc | AP2156SG-13 | 5.5V | 0.5A/ch | Digi-Key | http://www.digikey.com/product-detail/en/AP2156SG-13/AP2156SGDICT-ND/2057320 | AP2156SGDICT-ND | 0.387
U3 | 1 | USB2517 | QFN-64-PAD | SMSC | USB2517I-JZX | 3.3v | 240mA | Mouser | http://ca.mouser.com/ProductDetail/Microchip/USB2517I-JZX/ | 886-USB2517I-JZX | 5.29
U4 | 1 | TLE4284DV33 | V-REG_DPACK | Infineon | TLE4284D V33 | 3.3V | 1A | Digi-Key | http://www.digikey.ca/product-detail/en/TLE4284D%20V33/TLE4284D%20V33TR-ND/1016100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 | TLE4284D V33TR-ND | 1.025
Y1 | 1 | 24M | HC49USX | ECS | ECS-240-12-5PX-TR | 50ppm | 12pF | Digi-Key | http://www.mouser.com/ProductDetail/ECS/ECS-240-12-5PX-TR/ | 520-ECS-240-12-5PX-T | 0.2
R39,42,44,46,48,50,52 | 7 | 0 | 0402-RES | KOA Speer | RK73Z1ETTP | -% | 1W | Mouser | http://ca.mouser.com/ProductDetail/KOA-Speer/RK73Z1ETTP/ | 660-RK73Z1ETTP | 0.021

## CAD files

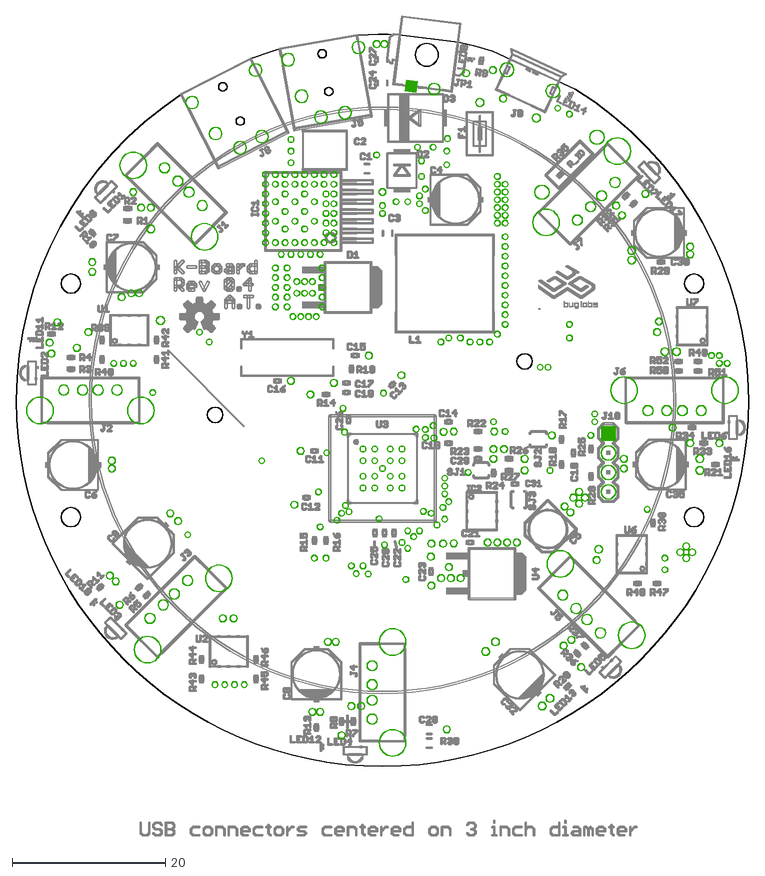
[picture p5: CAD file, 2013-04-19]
schematics/fabrication/Dock.dxf
95.5 x 107.0

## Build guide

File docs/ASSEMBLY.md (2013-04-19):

Dock Assembly Instructions
==========================

Special Assembly Instructions
-----------------------------

*	See NOTES: on ASSY drawings for general notes
*	Ensure no excess solder is wicked into J0 (USB Micro Connector).  Verify a
	USB Micro cable can successfully connect
*	Ensure J0 (USB Micro Connector) is completely flush to the PCB before/after
	reflow.  Ensure pins at rear of connector are not lifted off pads.
*	Apply epoxy to J0 for additional structural rigidity

Gerber output instructions
--------------------------

*	Verify silkscreen and PCB Frame artwork reflects accurate revision
*	Delete all content on layer (144) DrillLegend
*	run "drillegend.ulp": Use all default values, click OK.
*	Reselect layer (144) and move the newly created drill legend back onto the
	frame
*	Verify SSC-EAGLE-4Lyr_v1.0.0.3.dru is loaded as current design rules file
*	Turn on all copper and stopmask layers, turn off silkscreen layers (skip
	silkscreen error checking, silkscreen will be clipped by assembly house)
*	Preform DRC/ERC check
*	run "drillcfg.ulp": select "Inch" as output format.  Click OK.  Save.
*	run "excellon.cam" in the CAM processor, click "Process Job"
*	run "4LPlus-Sunstone.cam" in the CAM processor, click "Process Job"
*	Double check all gerber files using a gerber file viewer (like gerbv).
*	Deselect all layers, select only the following layers:
	(17)Pads, (18)Vias, (20)Dimension, (21)tPlace, (22)bPlace, (23)tOrigins,
	(24)bOrigins, (25)tNames, (49)Reference, (51)tDocu, (52)bDocu
*	run "dxf.ulp": deselect "Fill Areas", make sure "mm" is selected under the
	"units" header.  Save the DXF file.
*	Deselect all layers, select only the following layers:
	(17)Pads, (18)Vias, (20)Dimension, (21)tPlace, (23)tOrigins, (25)tNames,
	(48)Document, (49)Reference, (51)tDocu, (144)DrillLegend
*	Hit print (Ctrl+P), select "Print to File (PDF)" as the printer, select
	Dock_ASSY.pdf, paper size A4, scale factor 1.  Click OK.
*	Deselect all layers, select only the following layers:
	(1)Top, (16)Bottom, (17)Pads, (18)Vias, (20)Dimension, (21)tPlace,
	(22)bPlace, (25)tNames, (51)tDocu, (52)bDocu
*	Zoom in so that PCB is centered in the screen and fills the window as much
	as possible.
*	Select File->Export->Image.  Select Dock.brd.png.  Set "Resolution" to 600.
	Set "Area" to "Window".
*	In the schematic window, hit print (Ctrl+P), select "Print to File (PDF)" as
	the printer, select Dock.sch.pdf, paper size A4, scale factor 1, page limit
	1  *	lick OK.
*	In the schematic window, select File->Export->Partlist.  Select
	"Dock.parts.txt".  Click OK.
*	Manually compare "Dock.parts.txt" to "Dock_bom.xls".  Make sure the two
	lists are consistent.
*	Open "CHANGELOG.xls".  Update the file to reflect the new revision.
*	Create a zip archive with the following files (at least):
	*	Dock_sch.pdf
	*	Dock.brd.png
	*	Dock_ASSY.pdf
	*	Dock.tsp
	*	Dock.L1
	*	Dock.L2
	*	Dock.L3
	*	Dock.L4
	*	Dock.smt
	*	Dock.smb
	*	Dock.slk
	*	Dock.oln
	*	Dock.gpi
	*	Dock.dxf
	*	Dock.drl
	*	Dock.dri
	*	Dock.drd
	*	Dock.bsp
	*	Dock.bsk
	*	Dock_bom.xls
	*	Dock.sch
	*	Dock.brd
	*	CHANGELOG.xls

Gerber file descriptions:
-------------------------

*	.L1 	Top Copper Layer
*	.L2		Layer 2 (Ground)
*	.L3		Layer 3 (VCC)
*	.L4		Bottom Copper Layer
*	.smt 	Top Soldermask
*	.slk 	Top Silkscreen
*	.tsp 	Top Solderpaste
*	.smb 	Bottom Soldermask
*	.bsk 	Bottom Silkscreen
*	.bsp 	Bottom Solderpaste
*	.oln	PCB Outline
*	.drd 	Excellon Drill Data
*	.drl 	Basic Drill tool information
*	.dri 	Extended Drill tool information

Factory Testing Plan
--------------------

A test jig can be created using [Spring Pogo
Pins](https://www.adafruit.com/products/394).  At a minimum, the test jig should
contain pogo pins and mounting holes at the PCB locations outlined in the
Dock_polog_locations.xls spreadsheet. A rooted linux host is necessary for this
test - perhaps an embedded android device like a Raspberry Pi, Beagleboard or
pcDuino.

1.	Apply 12V power to board
1.	Measure all power rails, verify they are within 0.1V of target
1.	Read voltage level at PWR0-PWR6 pins, verify accessory ports have valid
	power
1.	Read logic level at ERR0-ERR6 pins, verify all pins are HIGH
1.	Remove +12V power, attach +5V supply to the Micro USB port
1.	Re-verify power rails are within range
1.	Re-apply 12V power to board
1. 	Connect USB to linux host
1.	Examine lsusb, /var/log/kern.log and /sys/bus/usb/ to verify Hub has
	enumerated successfully
1.	Attach a valid USB device to each port, for each port Examine lsusb,
	/var/log/kern.log and /sys/bus/usb/ to verify USB device has enumerated
	successfully
1.	Attach a shorted USB device to each port, verify LED turns red, verify the
	associated ERRX pin has fallen, verify lsusb and /sys/bus/usb notices the
	power fault

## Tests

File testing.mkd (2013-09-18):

**USB**

* Maintain a transfer rate of at least 30MB/s for a sustained 100MB transfer over USB with no transmission errors
* Measure sustained USB throughput when all USB ports are pushing data over 12 hours
* Using USB debugger, verify the expected USB protocol sequence when plugging/unplugging

**Power**

* Verify available current on each port when all ports draw power
* Verify voltage/current stays within limits at all ports through connect/disconnect cycles
* Verify an Android device attached to center USB port can both act as a USB OTG host and connect to the hub as well as be charged with 5v power.

**Physical**

* Fits into a variety of cup holders
* Robust connection between cup holder piece and top piece
* Secure mechanical fit between iJoeys and K-board, consider yield point and Young's Modulus of desired material
* K-board must be able to go through 100 attach/detach procedures with the cup holder piece with no visible wear
* K-board must be able to go through 100 attach/detach procedures with the iJoey with no visible wear

**Mechanical**

* Designed for injection molding --> Constant wall thickness, appropriate minimum thickness material (0.050" for ABS), draft angles, slide consideration
* Robust attachment and mating features between housing pieces
* Appropriate fit in specified vehicles (Focus, Flex, F-150, Explorer)

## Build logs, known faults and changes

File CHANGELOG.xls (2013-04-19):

What | Where | Criteria | done? | Severity | Notes
R0.1
Capacitor orientation errors | Schematic | C7, C9, C32, C35 are wired backwards in schematic | YES | 3 | Reworkable
Capacitor size errors | Layout/BOM | C4-9 + C30-35 are one size larger on layout VS BOM | YES | 2 | Smaller parts fit on larger footprint
LED Orientation | Layout | LED 1-7 has incorrect footprint, pins 1 and 3 swapped | YES | 4 | LEDs can be temporarily flipped, but green channel becomes inoperable
R0.2
USB connector pinout | Schematic | All Downstream USB sockets have VCC and GND swapped | YES | 5
Crystal capacitance | Schematic | Change to 18-22pf | YES | 2
Swap red and green LED lines | Schematic |  | YES | 4
USB Shield Ground | Schematic | Separate ground for USB Shields, decoupled to signal ground through 1M resistor and 4.7nF capacitor in parallel | YES | 2 | Capacitor should have very high voltage rating 250VAC if possible, traces should be as large as possible.
Remove LED15 | Schematic | We need to force HS_IND LOW on boot | YES | 3
R0.3
Swap D+/D- | layout | Check impact on layout, an EEPROM can be added also | YES | 5
5V power input logic | Schematic | Consider only permitting +5V from USB if no +12V is present | Partial | 2 | Power logic not added, but PTC Resettable fuse added.
Excess solder reflow on USB shield | Assembly Notes | Work with CM to avoid this issue. | YES | 3 | Added to assembly notes
Enable power switches when no USB host is active | Schematic | Either switch USB Hub, add transistor logic, or force power switch to be always on | YES | 3 | Added jumper resistor options to either force switch on or enable HUB control
Light red error LED when switch is overcurrent and no USB host is active | Schematic | Either switch USB Hub, or add transistor logic | NO | 2 | Would add too many parts, too much risk of interrupting hub error detection
Add reverse current protecton | Schematic | In reverse current scenario, protect D2 from excessive current | YES | 2
Add pogo pins for future testing | Layout |  | YES | 2 | Pogo pins added to bottom layer
R0.4
Change Resistor Values for status LEDs | BOM | Make Status LEDs brighter so that indication is easier to see | YES | 1 | Changed R1-8,31-34,36,37 to 110 ohm
Severity:
1: Purely Optional or Cosmetic
2: Enhancing reliability or robustness
3: A reworkable error
4: Not easily reworked, noncritical
5: Critical to main board operation

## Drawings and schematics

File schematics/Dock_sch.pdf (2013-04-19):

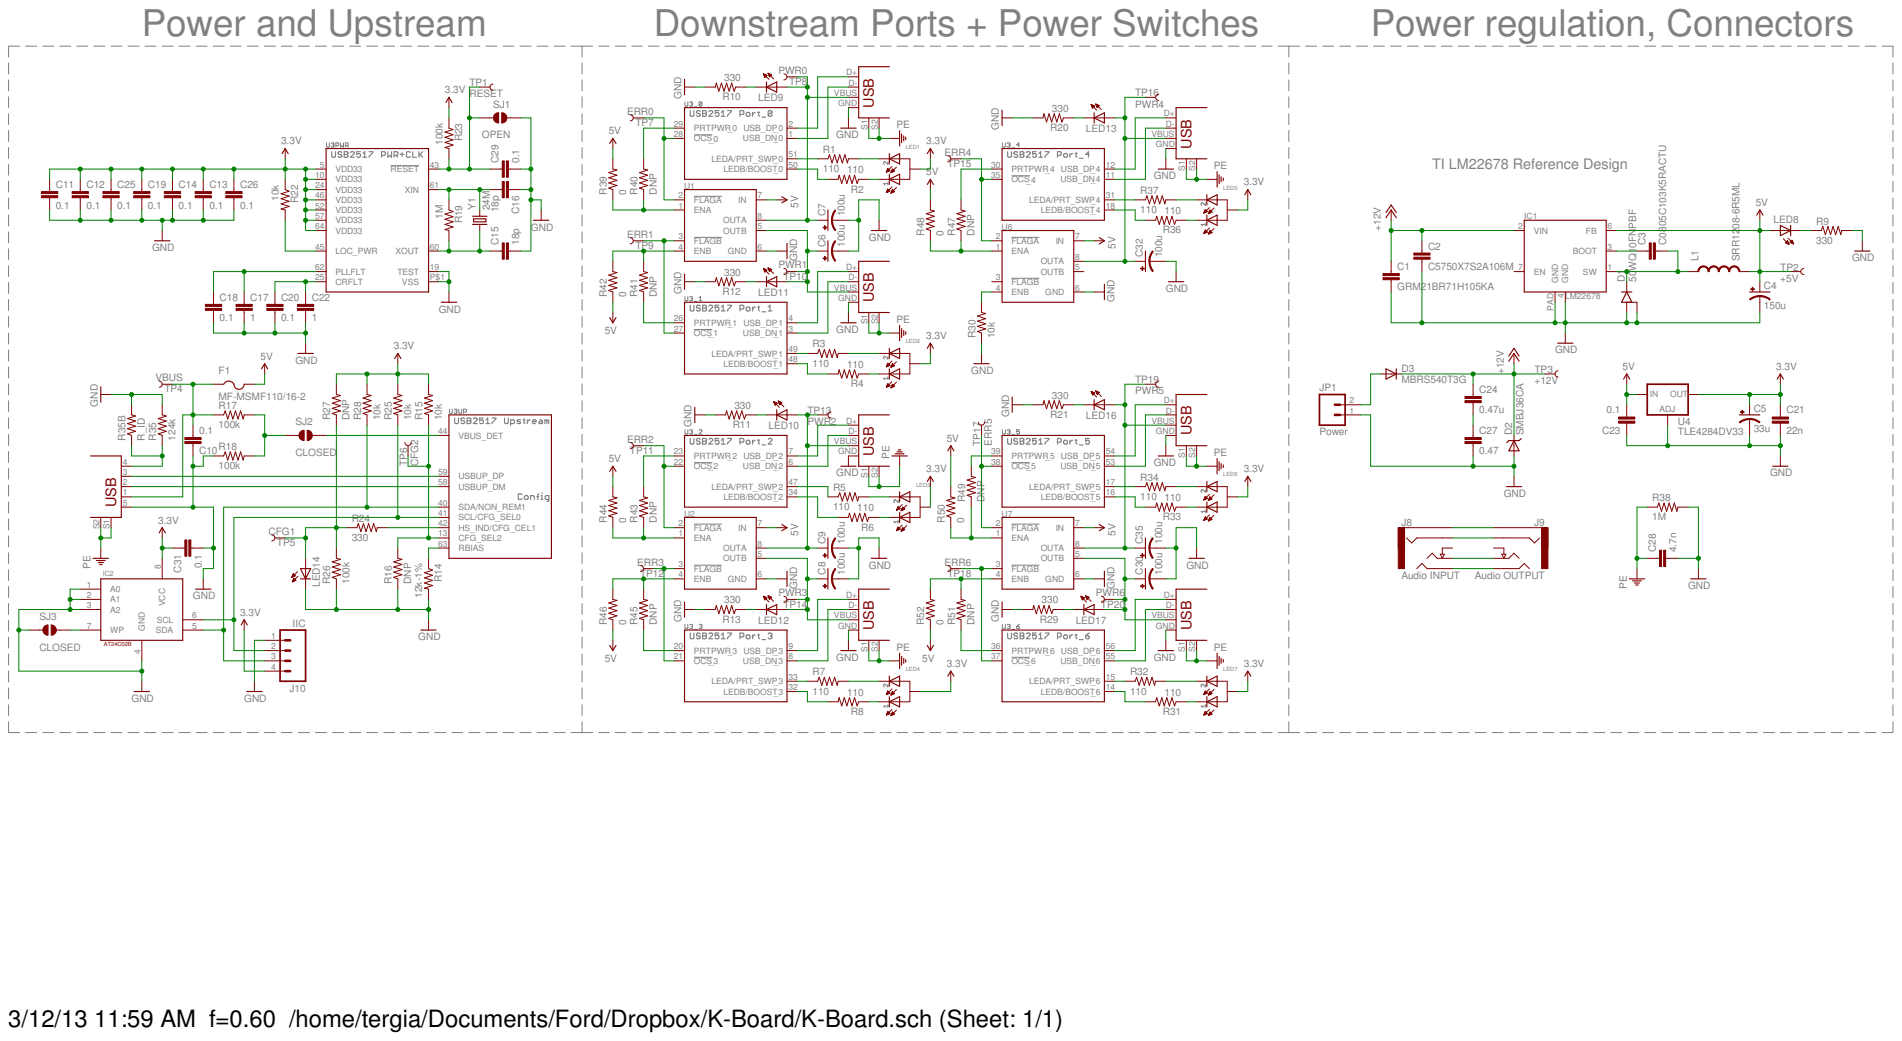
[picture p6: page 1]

USB USB

Audio INPUT Audio OUTPUT

3/12/13 11:59 AM f=0.60 /home/tergia/Documents/Ford/Dropbox/K-Board/K-Board.sch (Sheet: 1/1)

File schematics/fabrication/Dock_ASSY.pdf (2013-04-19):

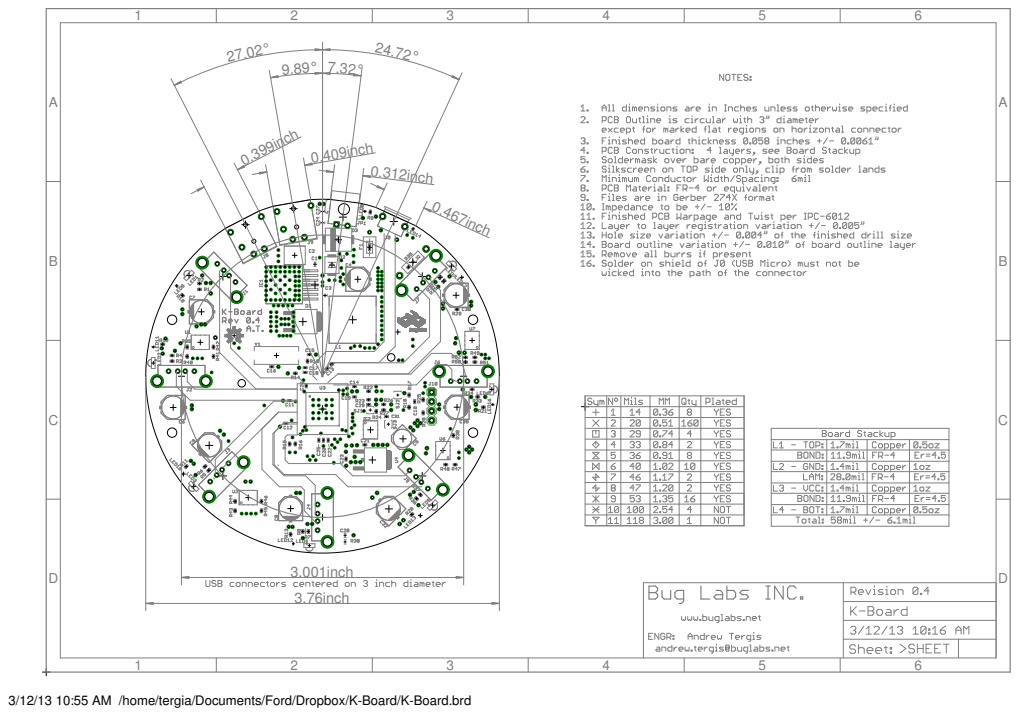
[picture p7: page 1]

3/12/13 10:55 AM /home/tergia/Documents/Ford/Dropbox/K-Board/K-Board.brd

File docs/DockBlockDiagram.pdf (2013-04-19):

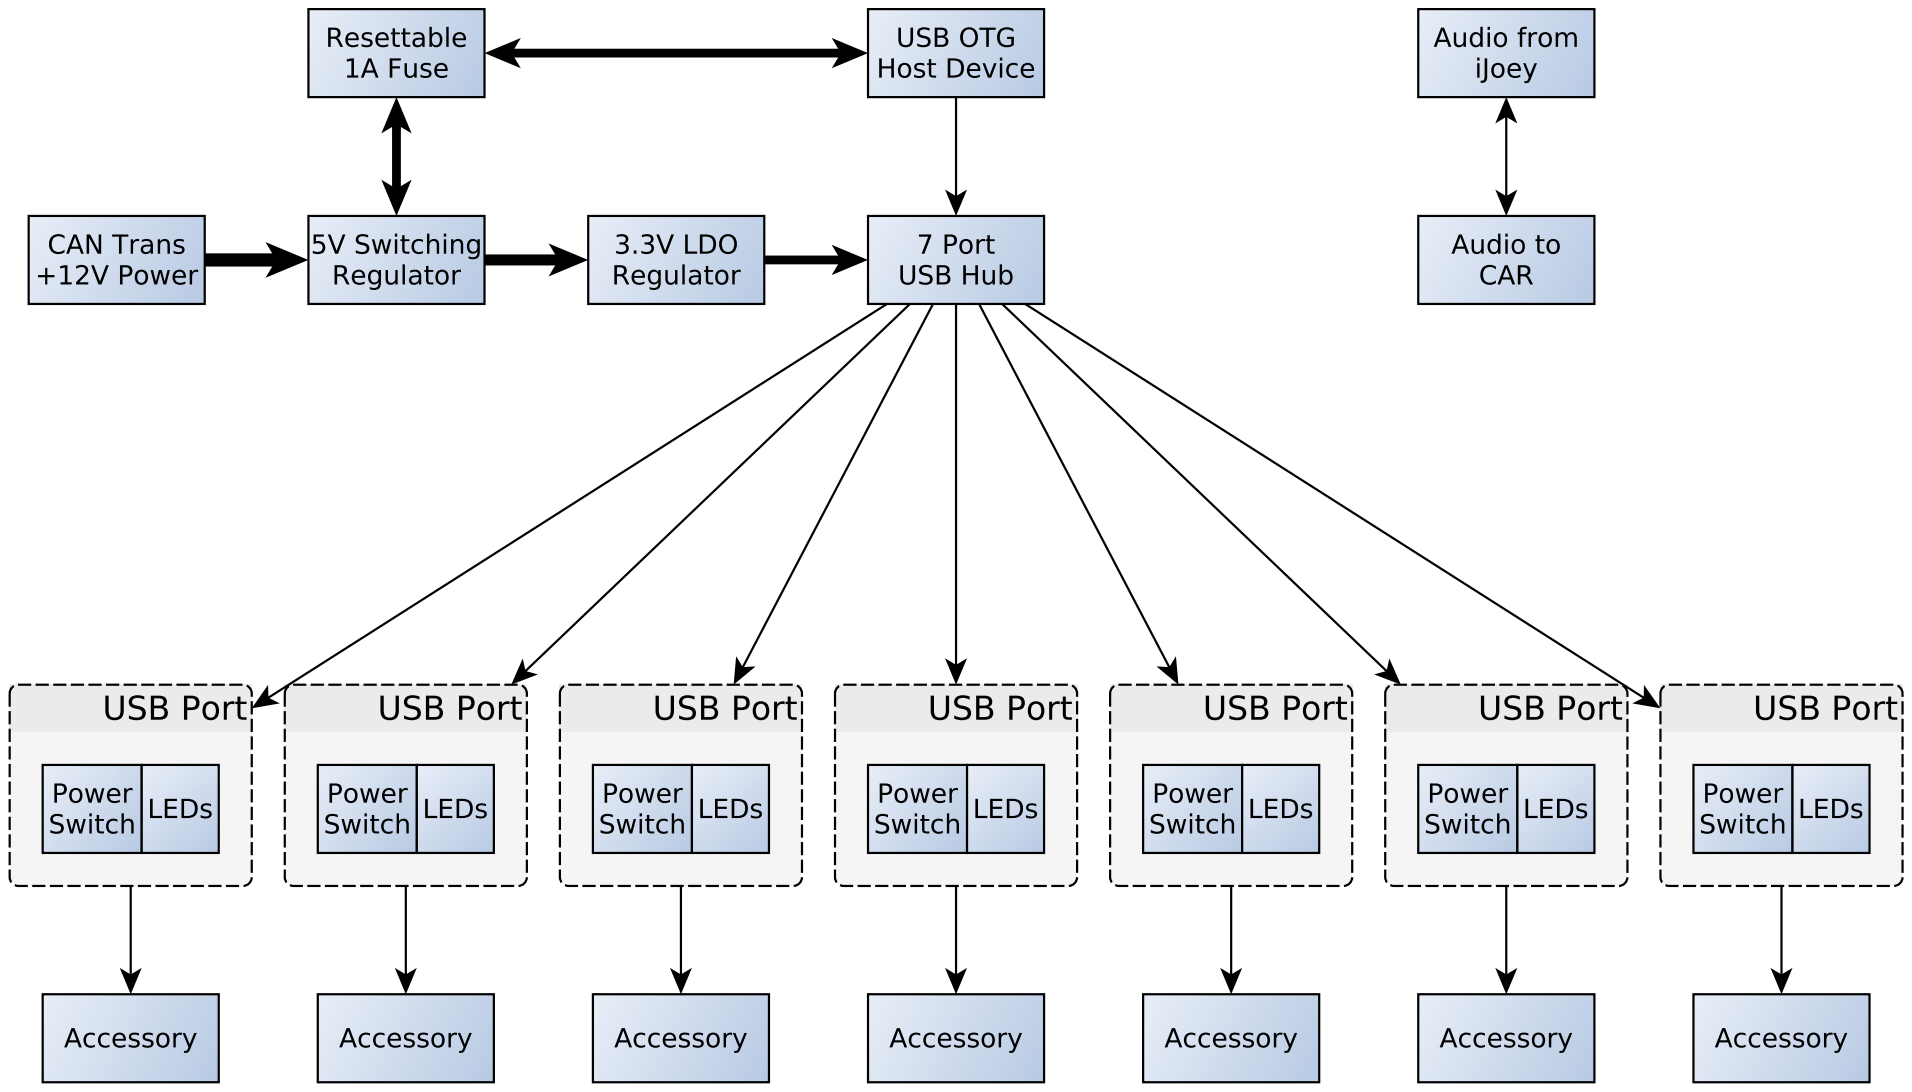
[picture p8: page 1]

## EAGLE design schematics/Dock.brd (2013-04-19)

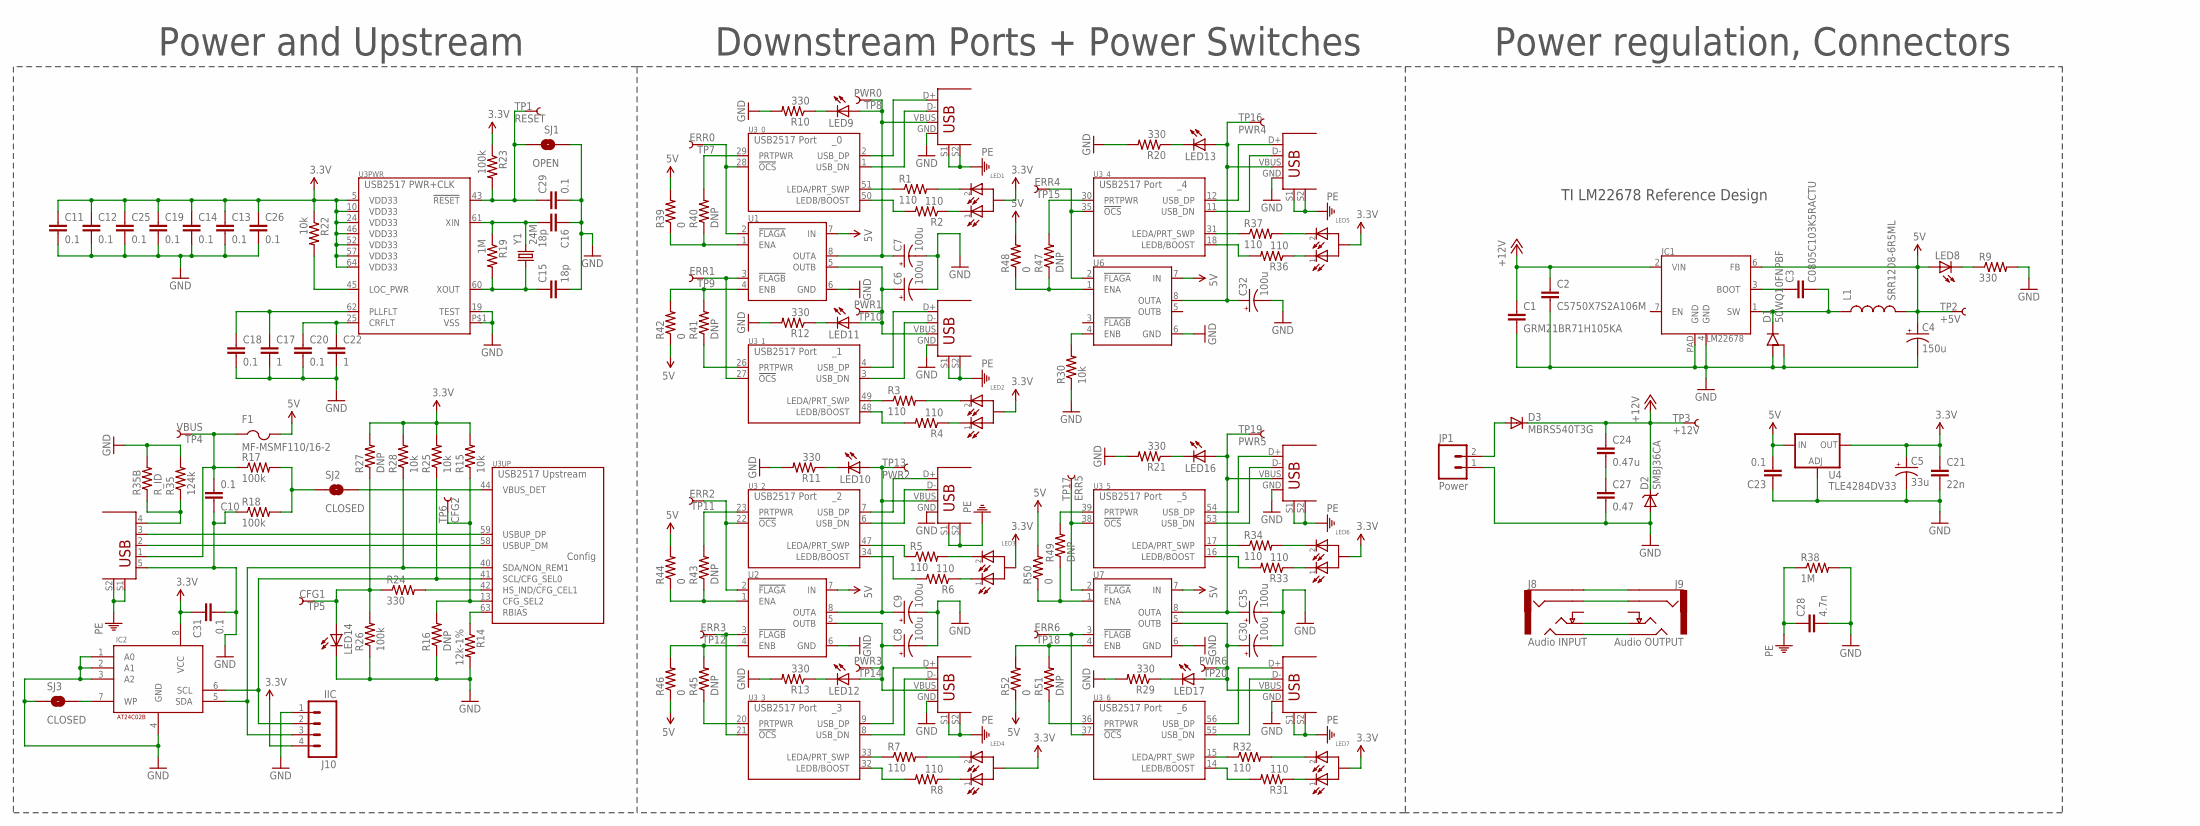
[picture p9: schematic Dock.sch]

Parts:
C1: GRM21BR71H105KA; 0805
C2: C5750X7S2A106M; 2220
C3: C0805C103K5RACTU; 0805
C4: 150u; PANASONIC_D
C5: 33u; PANASONIC_C
C6, C7, C8, C9, C30, C32, C35: 100u; PANASONIC_D
C10, C11, C12, C13, C14, C18, C19, C20, C23, C25, C26, C29, C31: 0.1; 0402-CAP
C15, C16: 18p; 0402-CAP
C17, C22: 1; 0402-CAP
C21: 22n; 0402-CAP
C24: 0.47u; 0805
C27: 0.47; 0805
C28: 4.7n; 0805
D1: 50WQ10FNPBF; V-REG_DPACK
D2: SMBJ36CA; SMB-DIODE
D3: MBRS540T3G; SMC
F1: MF-MSMF110/16-2; 1812
IC1: LM22678; TO-263
IC2: ATMEL-AT24C02B-SS; SOIC8
J0: USB_MINIB_SHIELD-10118193; 10118193
J1, J2, J3, J4, J5, J6, J7: USB-A-S-RA-VERT; USB-A-TH-VERT
J8: Audio INPUT; SJ-4351X
J9: Audio OUTPUT; SJ-4351X
J10: IIC; 1X04
JP1: Power; 2-1445055-2
L1: SRR1208-6R5ML; SRR1208
LED1, LED2, LED3, LED4, LED5, LED6, LED7: LED_2X_COMMON_ANODE; LED_DUAL_3MMX1MM
LED8, LED9, LED10, LED11, LED12, LED13, LED14, LED16, LED17: LED0603; LED-0603
R1, R2, R3, R4, R5, R6, R7, R8, R31, R32, R33, R34, R36, R37: 110; 0402-RES
R9, R10, R11, R12, R13, R20, R21, R24, R29: 330; 0402-RES
R14: 12k-1%; 0402-RES
R15, R22, R25, R28, R30: 10k; 0402-RES
R16, R27, R40, R41, R43, R45, R47, R49, R51: DNP; 0402-RES
R17, R18, R23, R26: 100k; 0402-RES
R19: 1M; 0402-RES
R35: 124k; 0402-RES
R35B: R_ID; AXIAL-0.4
R38: 1M; 0805
R39, R42, R44, R46, R48, R50, R52: 0; 0402-RES
SJ1: OPEN; SJ_2S-NO
SJ2, SJ3: CLOSED; SJ_2S-TRACE
TP1: RESET; PAD.03X.03
TP2: +5V; PAD.03X.03
TP3: +12V; PAD.03X.03
TP4: VBUS; PAD.03X.03
TP5: CFG1; PAD.03X.03
TP6: CFG2; PAD.03X.03
TP7: ERR0; PAD.03X.03
TP8: PWR0; PAD.03X.03
TP9: ERR1; PAD.03X.03
TP10: PWR1; PAD.03X.03
TP11: ERR2; PAD.03X.03
TP12: ERR3; PAD.03X.03
TP13: PWR2; PAD.03X.03
TP14: PWR3; PAD.03X.03
TP15: ERR4; PAD.03X.03
TP16: PWR4; PAD.03X.03
TP17: ERR5; PAD.03X.03
TP18: ERR6; PAD.03X.03
TP19: PWR5; PAD.03X.03
TP20: PWR6; PAD.03X.03
U1, U2, U6, U7: MIC2026; SOIC8
U3: USB2517; QFN-64-PAD
U4: TLE4284DV33; V-REG_DPACK
Y1: 24M; HC49USX

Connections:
3.3V: C5.+, C11.1, C12.1, C13.1, C14.1, C19.1, C21.1, C25.1, C26.1, C31.1, IC2.8 (VCC), J10.4, LED1.1 (A), LED2.1 (A), LED3.1 (A), LED4.1 (A), LED5.1 (A), LED6.1 (A), LED7.1 (A), R15.2, R22.1, R23.1, R25.2, R27.2, R28.2, U3.5 (VDD33), U3.10 (VDD33), U3.24 (VDD33), U3.46 (VDD33), U3.52 (VDD33), U3.57 (VDD33), U3.64 (VDD33), U4.4 (OUT)
5V: C4.+, C23.2, F1.2, IC1.6 (FB), L1.2, LED8.A, R39.2, R42.1, R44.2, R46.1, R48.2, R50.2, R52.1, TP2.P$1, U1.7 (IN), U2.7 (IN), U4.3 (IN), U6.7 (IN), U7.7 (IN)
+12V: C1.1, C2.1, C24.1, D2.C, D3.C, IC1.2 (VIN), TP3.P$1
ENB3: R45.2, R46.2, U2.4 (ENB)
ENB6: R51.2, R52.2, U7.4 (ENB)
GND: C1.2, C2.2, C4.-, C5.-, C6.-, C7.-, C8.-, C9.-, C10.1, C11.2, C12.2, C13.2, C14.2, C15.2, C16.1, C17.2, C18.2, C19.2, C20.2, C21.2, C22.2, C23.1, C25.2, C26.2, C27.2, C28.2, C29.2, C30.-, C31.2, C32.-, C35.-, D1.1 (A), D1.3 (A), D2.A, IC1.4 (GND), IC1.PAD (GND), IC2.1 (A0), IC2.2 (A1), IC2.3 (A2), IC2.4 (GND), J0.5 (GND), J1.GND, J2.GND, J3.GND, J4.GND, J5.GND, J6.GND, J7.GND, J10.1, JP1.1, LED14.C, R9.2, R10.2, R11.2, R12.2, R13.2, R14.2, R16.1, R18.1, R20.2, R21.2, R26.1, R29.2, R30.1, R35.2, R35B.P$2 (2), R38.2, SJ1.1, SJ3.1, U1.6 (GND), U2.6 (GND), U3.19 (TEST), U3.P$1 (VSS), U4.1 (ADJ), U6.6 (GND), U7.6 (GND)
J7: J7.D+, U3.56 (USB_DP)
unnamed: C20.1, C22.1, U3.25 (CRFLT)
unnamed: R22.2, U3.45 (LOC_PWR)
unnamed: C17.1, C18.1, U3.62 (PLLFLT)
unnamed: C29.1, R23.2, SJ1.2, TP1.P$1, U3.43 (!RESET)
unnamed: C15.1, R19.2, U3.60 (XOUT), Y1.P$1 (1)
unnamed: C16.2, R19.1, U3.61 (XIN), Y1.P$2 (2)
unnamed: R30.2, U6.4 (ENB)
unnamed: R17.2, R18.2, SJ2.1
unnamed: J1.D-, U3.1 (USB_DN)
unnamed: SJ2.2, U3.44 (VBUS_DET)
unnamed: C10.2, F1.1, J0.1 (VBUS), R17.1, TP4.P$1
unnamed: R14.1, U3.63 (RBIAS)
unnamed: J1.D+, U3.2 (USB_DP)
unnamed: R2.2, U3.50 (LEDB/BOOST)
unnamed: R1.1, U3.51 (LEDA/PRT_SWP)
unnamed: LED1.3 (C2), R1.2
unnamed: LED1.2 (C1), R2.1
unnamed: TP7.P$1, U1.2 (!FLAGA), U3.28 (!OCS)
unnamed: R40.2, U3.29 (PRTPWR)
unnamed: C7.+, J1.VBUS, LED9.A, TP8.P$1, U1.8 (OUTA)
unnamed: R41.1, U3.26 (PRTPWR)
unnamed: TP9.P$1, U1.3 (!FLAGB), U3.27 (!OCS)
unnamed: J2.D-, U3.3 (USB_DN)
unnamed: J2.D+, U3.4 (USB_DP)
unnamed: C6.+, J2.VBUS, LED11.A, TP10.P$1, U1.5 (OUTB)
unnamed: LED2.3 (C2), R3.2
unnamed: R4.2, U3.48 (LEDB/BOOST)
unnamed: R3.1, U3.49 (LEDA/PRT_SWP)
unnamed: LED2.2 (C1), R4.1
unnamed: J6.D-, U3.53 (USB_DN)
unnamed: J3.D-, U3.6 (USB_DN)
unnamed: J3.D+, U3.7 (USB_DP)
unnamed: R6.2, U3.34 (LEDB/BOOST)
unnamed: R5.1, U3.47 (LEDA/PRT_SWP)
unnamed: LED3.3 (C2), R5.2
unnamed: LED3.2 (C1), R6.1
unnamed: LED11.C, R12.1
unnamed: J4.D-, U3.8 (USB_DN)
unnamed: J4.D+, U3.9 (USB_DP)
unnamed: C8.+, J4.VBUS, LED12.A, TP14.P$1, U2.5 (OUTB)
unnamed: LED4.3 (C2), R7.2
unnamed: R8.2, U3.32 (LEDB/BOOST)
unnamed: R7.1, U3.33 (LEDA/PRT_SWP)
unnamed: LED4.2 (C1), R8.1
unnamed: TP11.P$1, U2.2 (!FLAGA), U3.22 (!OCS)
unnamed: R43.2, U3.23 (PRTPWR)
unnamed: D3.A, JP1.2
unnamed: TP12.P$1, U2.3 (!FLAGB), U3.21 (!OCS)
unnamed: J5.D-, U3.11 (USB_DN)
unnamed: J5.D+, U3.12 (USB_DP)
unnamed: R36.2, U3.18 (LEDB/BOOST)
unnamed: R37.1, U3.31 (LEDA/PRT_SWP)
unnamed: LED5.3 (C2), R37.2
unnamed: LED5.2 (C1), R36.1
unnamed: C32.+, J5.VBUS, LED13.A, TP16.P$1, U6.8 (OUTA)
unnamed: J6.D+, U3.54 (USB_DP)
unnamed: R33.2, U3.16 (LEDB/BOOST)
unnamed: R34.1, U3.17 (LEDA/PRT_SWP)
unnamed: LED6.3 (C2), R34.2
unnamed: LED6.2 (C1), R33.1
unnamed: C35.+, J6.VBUS, LED16.A, TP19.P$1, U7.8 (OUTA)
unnamed: J7.D-, U3.55 (USB_DN)
unnamed: J8.3 (RING1), J9.3 (RING1)
unnamed: C30.+, J7.VBUS, LED17.A, TP20.P$1, U7.5 (OUTB)
unnamed: LED7.3 (C2), R32.2
unnamed: R31.2, U3.14 (LEDB/BOOST)
unnamed: R32.1, U3.15 (LEDA/PRT_SWP)
unnamed: LED7.2 (C1), R31.1
unnamed: TP15.P$1, U3.35 (!OCS), U6.2 (!FLAGA)
unnamed: R47.2, U3.30 (PRTPWR)
unnamed: TP17.P$1, U3.38 (!OCS), U7.2 (!FLAGA)
unnamed: R49.2, U3.39 (PRTPWR)
unnamed: TP18.P$1, U3.37 (!OCS), U7.3 (!FLAGB)
unnamed: R15.1, R16.2, TP6.P$1, U3.13 (CFG_SEL2)
unnamed: LED14.A, R24.1, R26.2, R27.1, TP5.P$1
unnamed: R24.2, U3.42 (HS_IND/CFG_CEL1)
unnamed: IC2.6 (SCL), J10.2, R25.1, U3.41 (SCL/CFG_SEL0)
unnamed: IC2.5 (SDA), J10.3, R28.1, U3.40 (SDA/NON_REM1)
unnamed: J8.2 (TIP), J9.2 (TIP)
unnamed: R39.1, R40.1, U1.1 (ENA)
unnamed: C3.1, IC1.3 (BOOT)
unnamed: J8.4 (RING2), J9.4 (RING2)
unnamed: J8.1 (SLEEVE), J9.1 (SLEEVE)
unnamed: LED8.C, R9.1
unnamed: LED9.C, R10.1
unnamed: C9.+, J3.VBUS, LED10.A, TP13.P$1, U2.8 (OUTA)
unnamed: LED10.C, R11.1
unnamed: C24.2, C27.1
unnamed: LED12.C, R13.1
unnamed: LED17.C, R29.1
unnamed: LED16.C, R21.1
unnamed: LED13.C, R20.1
unnamed: J0.4 (ID), R35.1, R35B.P$1 (1)
unnamed: R41.2, R42.2, U1.4 (ENB)
unnamed: R43.1, R44.1, U2.1 (ENA)
unnamed: R45.1, U3.20 (PRTPWR)
unnamed: R47.1, R48.1, U6.1 (ENA)
unnamed: R49.1, R50.1, U7.1 (ENA)
unnamed: R51.1, U3.36 (PRTPWR)
unnamed: IC2.7 (WP), SJ3.2
PE: C28.1, J0.S1, J0.S2, J1.S1, J1.S2, J2.S1, J2.S2, J3.S1, J3.S2, J4.S1, J4.S2, J5.S1, J5.S2, J6.S1, J6.S2, J7.S1, J7.S2, R38.1
SW: C3.2, D1.4 (C), IC1.1 (SW), L1.1
UP_DM: J0.2 (D-), U3.58 (USBUP_DM)
UP_DP: J0.3 (D+), U3.59 (USBUP_DP)

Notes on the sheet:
Power and Upstream
Downstream Ports + Power Switches
Power regulation, Connectors
TI LM22678 Reference Design

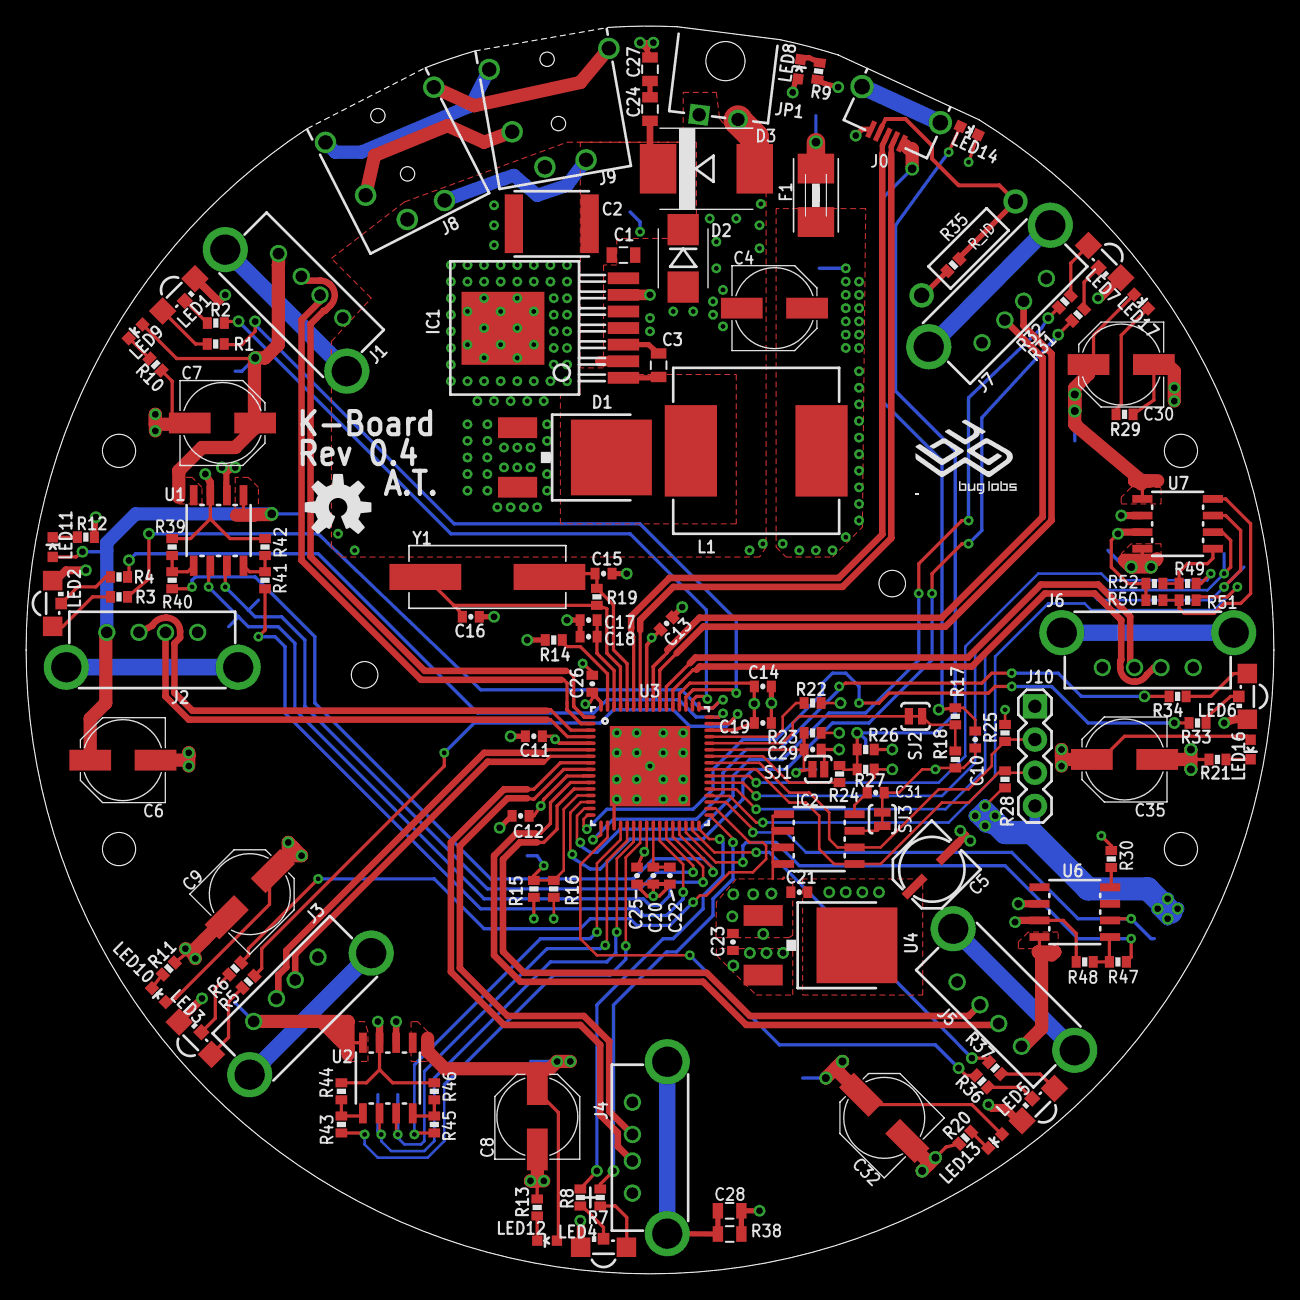
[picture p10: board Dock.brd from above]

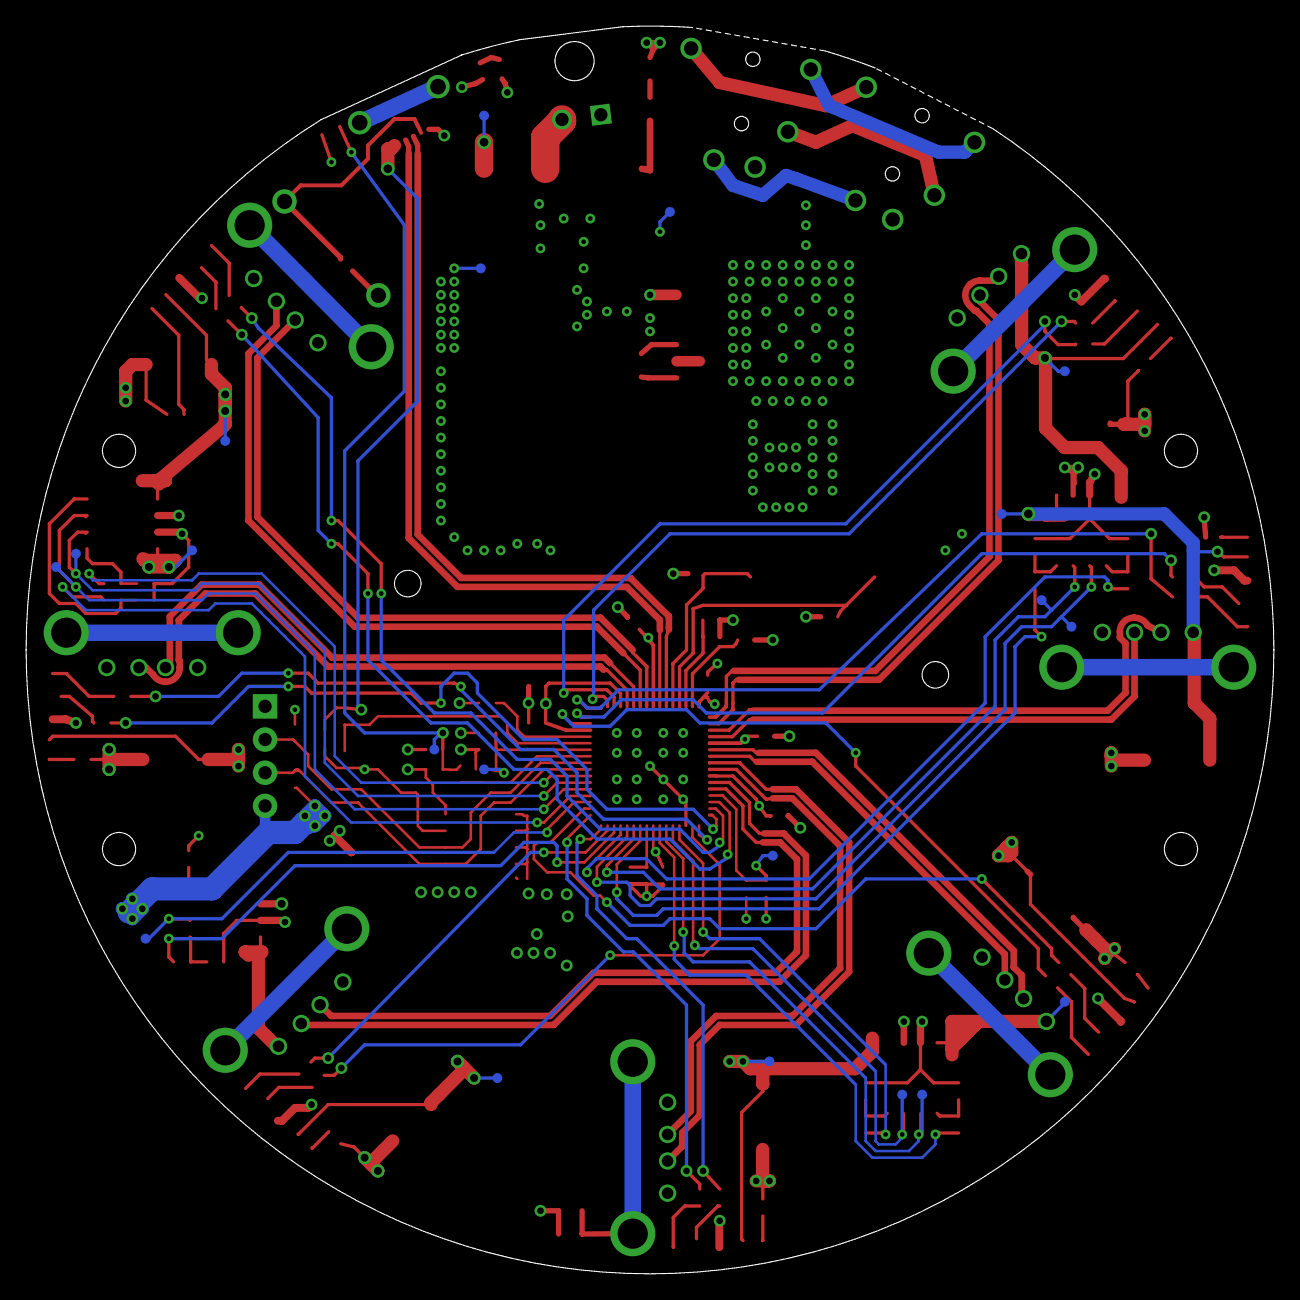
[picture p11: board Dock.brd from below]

Board: 4 copper layers, 95.5 x 95.5 mm, 155 parts (20 on the bottom side), 111 nets.

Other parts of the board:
DRILEGEND: DRILEGEND
SYM1: OSHW-LOGO-M
SYM2: BUG_LOGO_SM
U$9: A4L-LOC

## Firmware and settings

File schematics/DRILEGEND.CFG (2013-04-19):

InputUserCfg = 1
SymbolLayer = 144
SymbolSize = 40
SymbolWidth = 4
TextSize = 70.0000
TextRatio = 5
IdxFnt = 0
decMM = 2
decMIL = 0
SortHoles = 1
TolPlated = 0.001
TolNonPlated = 0.001
PlatedStatusNot = NOT
PlatedStatusBoth = BOTH
PlatedStatusYes = YES
VerticalChart = 1
HighCellFactor = 1.10
WideCellFactor = 1.10
CellOutline = 4
TitleOutline = 4
TableOutline = 8
SymbTitle = Sym
ToolTitle = N°
MMTitle = MM
MilTitle = Mils
MicTitle = Mic
QtyTitle = Qty
TypeTitle = Plated
ToleTitle = Tol
SymbRank = 1
ToolRank = 2
MMRank = 4
MilRank = 3
MicRank = 0
QtyRank = 5
TypeRank = 6
ToleRank = 0
OutputDrillRack = 0
DrillRackFile = DRILLRACK.DRL
Unit = 0
OutputUserCfg = 1
UserCfgFile = DRILEGEND.CFG

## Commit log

2013-04-19 Initial commit.
    [CHANGELOG.xls, DESIGN_CRITERIA.xls, DRILEGEND.CFG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]
2013-04-19 Update all K-board references to "Dock", including filenames.
    Also, remove references to iJoey and replace with "accessory".
    [Dock.brd, Dock.dxf, Dock.sch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]
2013-09-18 Add testing criteria as plaintext.
    [DESIGN_CRITERIA.xls]

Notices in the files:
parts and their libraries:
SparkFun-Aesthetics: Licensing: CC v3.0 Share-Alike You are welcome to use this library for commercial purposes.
